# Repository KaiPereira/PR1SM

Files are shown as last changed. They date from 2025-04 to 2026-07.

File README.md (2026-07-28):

# PR1SM - Stacked Acrylic Keyboard

PR1SM is a minimalistic, stacked acrylic keyboard with neopixel backlight, running on KMK. It's built on a cheap, compact 2 layer PCB and has a fully fledged TKL (tenkeyless) layout.

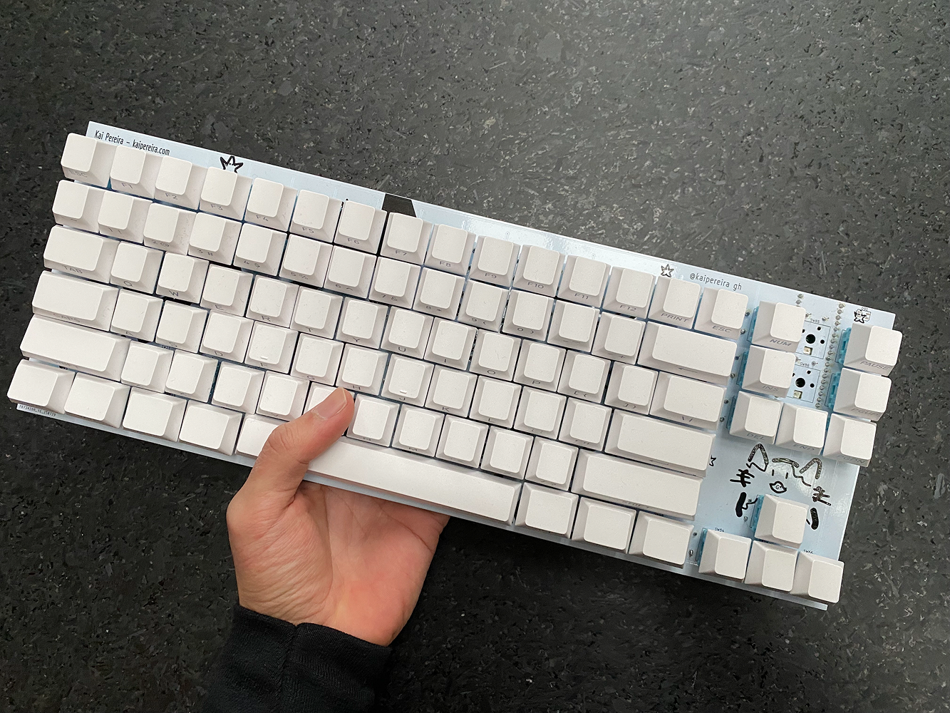
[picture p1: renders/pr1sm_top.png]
Pasted image 20250718024216.png

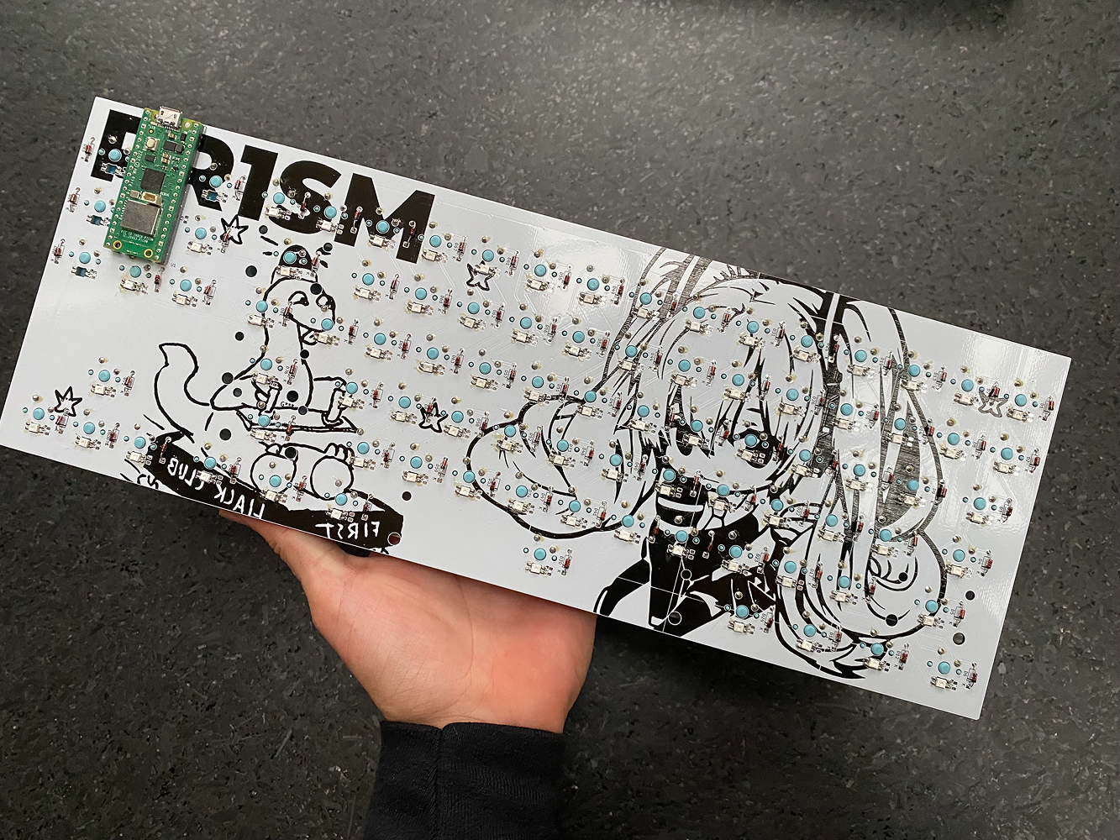
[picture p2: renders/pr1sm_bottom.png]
pr1sm bottom


## Custom Features
- Fully laser cut stacked case that will leak the RGB colors
- Full sized TKL (tenkeyless) layout with a function row
- Complete RGBA backlight on every single key with a power neopixel
- Decoupling caps, and stabilizing resistors for smooth power
- Simply runs off of a Raspberry Pi Pico
- Exposed black silkscreen design on a white PCB

## CAD Design

I used Onshape to design my keyboard like all of my projects. It was a bit tricky, because everything needed to be stock size and was going to be laser cut, so I couldn't have like partially cut in designs that a 3D printer could accomplish.

Anyways the entire case is just held together using M3 screws and it's all stacked so it should be decently rigid. The acrylic will let all the colors through, and it'll look sick.

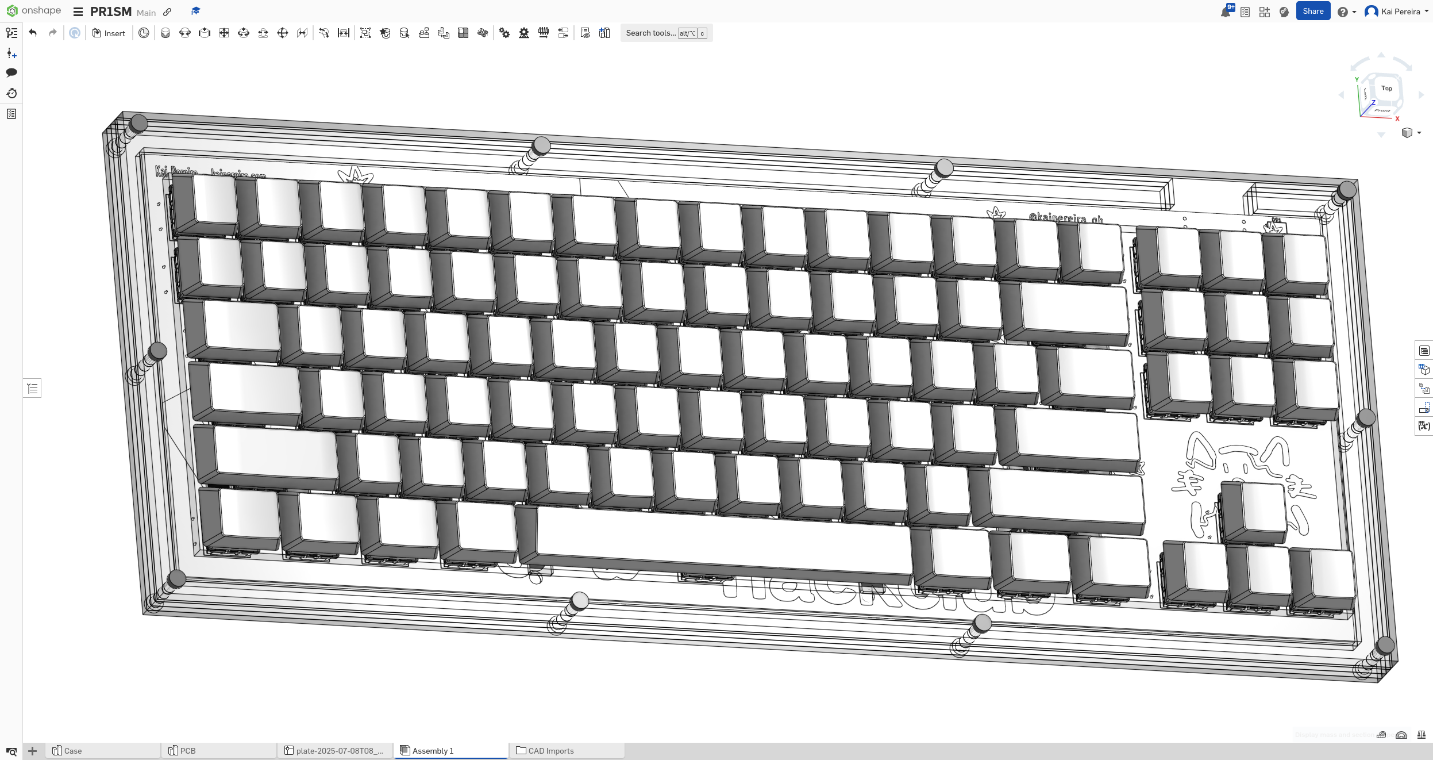
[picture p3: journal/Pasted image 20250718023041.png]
Pasted image 20250718023041.png

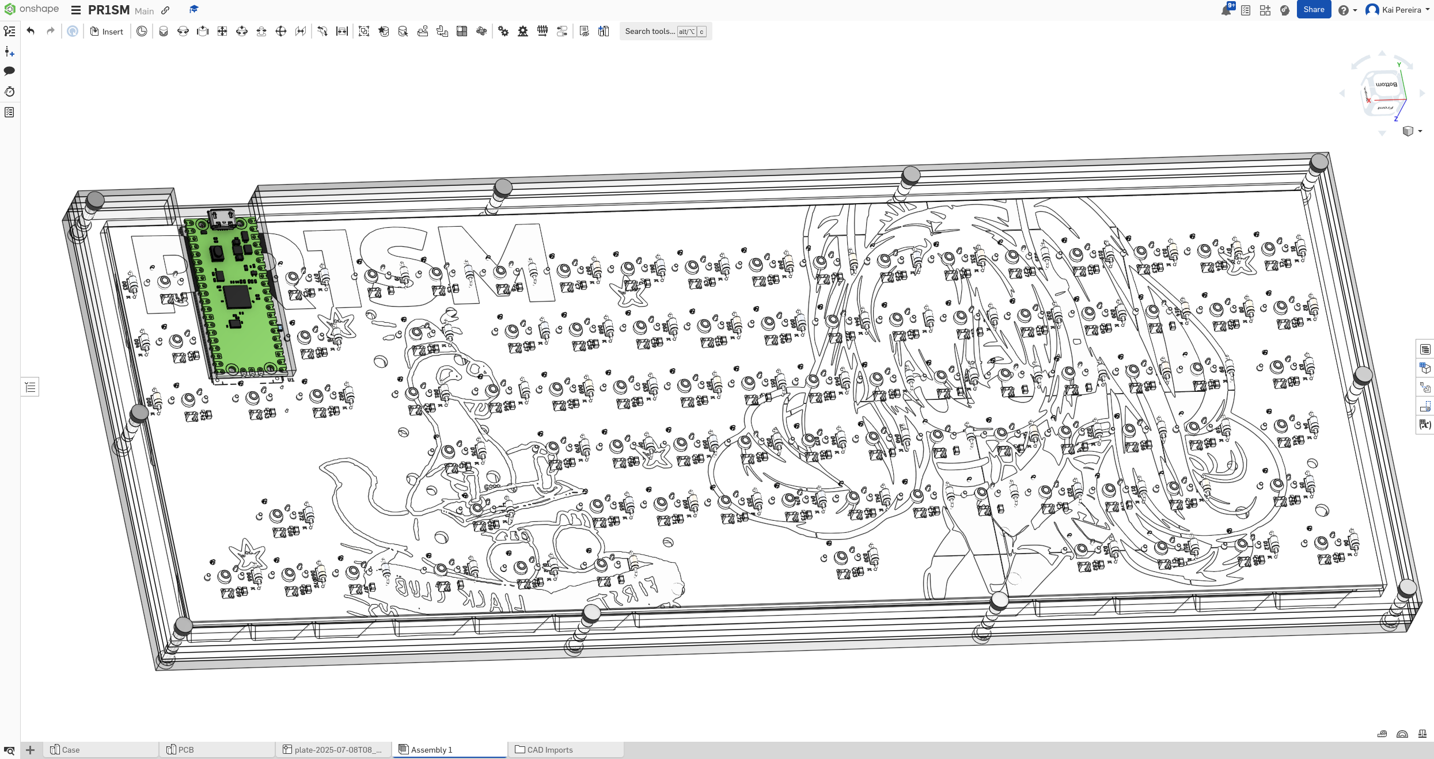
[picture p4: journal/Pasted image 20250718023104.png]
Pasted image 20250718023104.png


*The silkscreen is actually black as shown in the render*

The case is separated into 5 separate laser cut pieces, respectively 3 - 3.5mm, 1 - 1.5mm and 1 - 5mm plate so it's relatively thin and pretty easy to assemble. [Onshape Link](https://cad.onshape.com/documents/8b572caa0e2769c057d91df7/w/f3c5c8a5f25f2593dceb7e8f/e/dc4500617840d95f6da4efee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)

## PCB Design

I designed the entire PCB in KiCad. I tried to stick to all best practices and the neopixels have decoupling and a resistor to smooth voltage. The keys are just a simple key matrix, and the MCU is a Pi Pico. I used the KiCad image converter to do the images, and some of them are drawn by me, others are AI generated and then there's some taken from the internet.

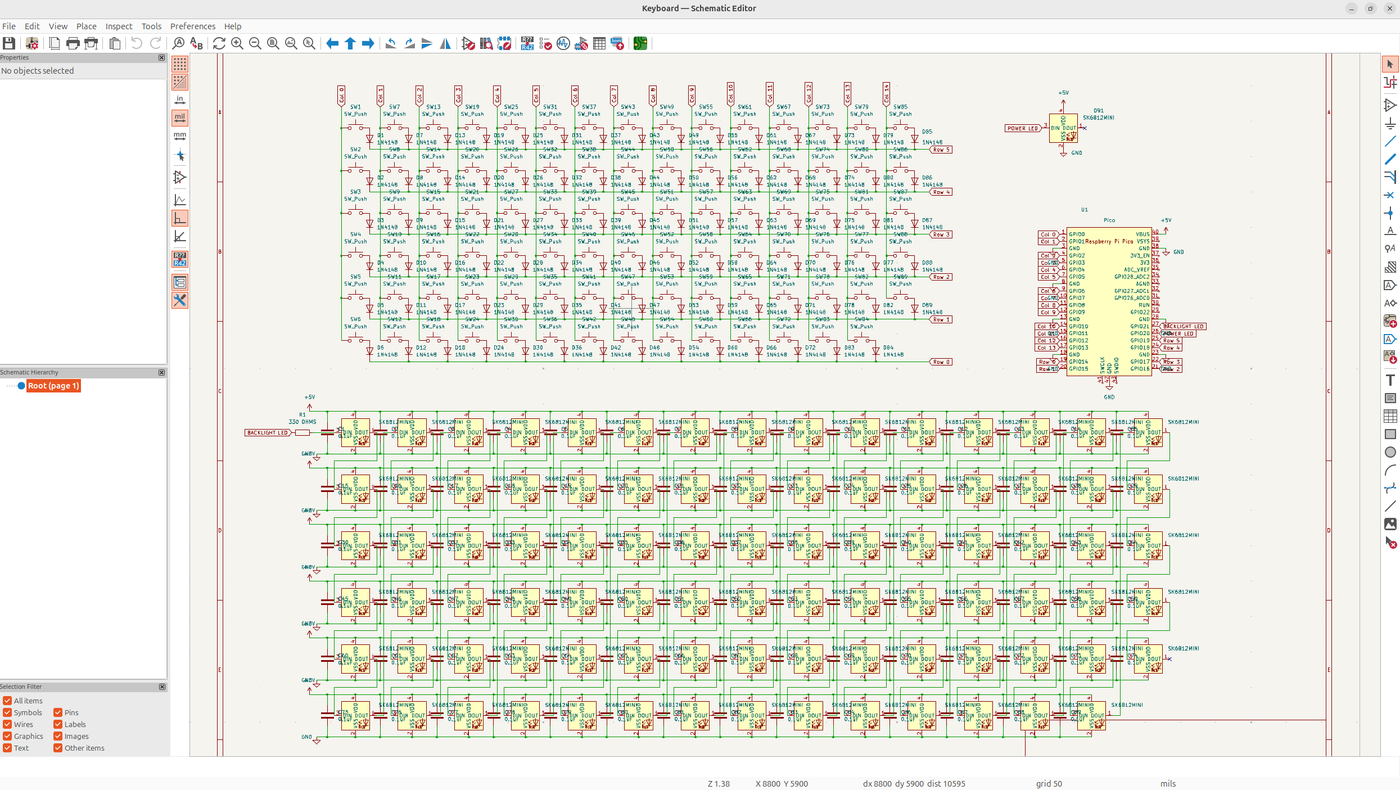
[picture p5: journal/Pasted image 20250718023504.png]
Pasted image 20250718023504.png


Now the PCB is a bit interesting, because it uses a ground fill on the bottom, and then a power fill on the top, the back lines run horizontally, while the front traces run vertically. Via's are on all the neopixel power lines for the fill with the decoupling caps right beside them.

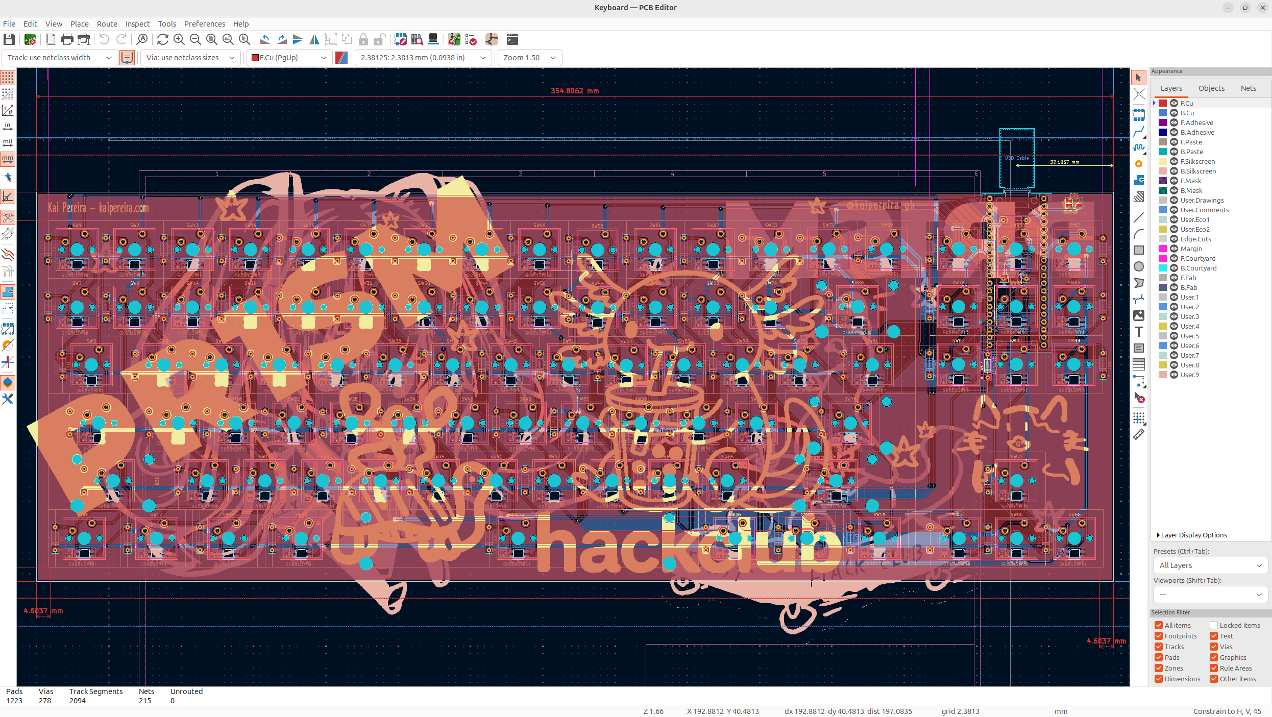
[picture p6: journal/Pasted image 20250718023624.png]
Pasted image 20250718023624.png


Some 3D photo's:

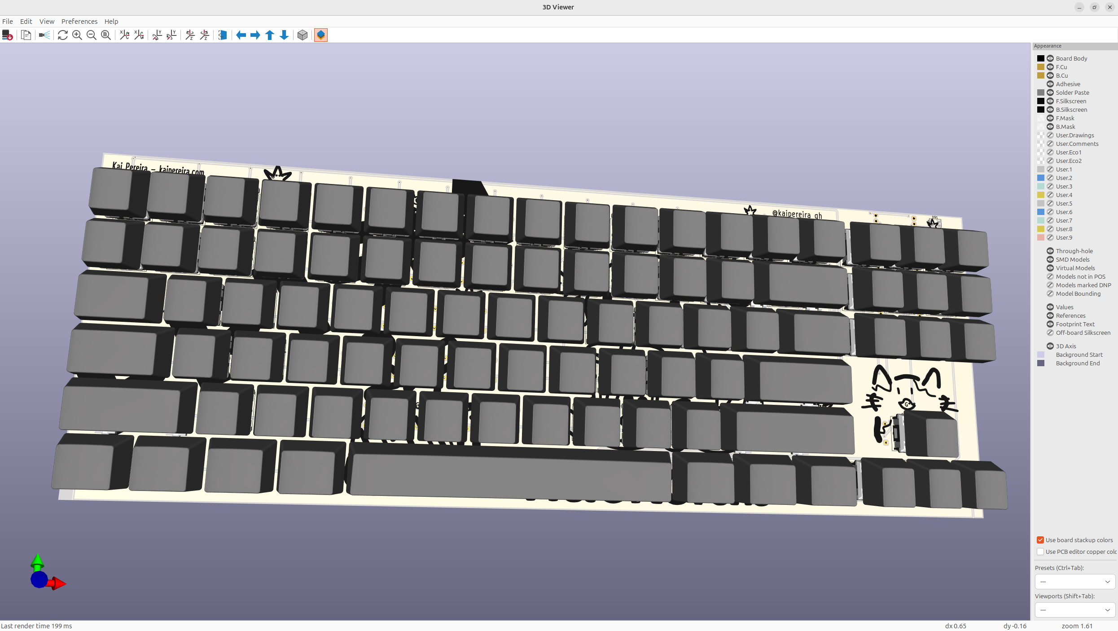
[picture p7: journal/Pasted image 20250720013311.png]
Pasted image 20250720013311.png

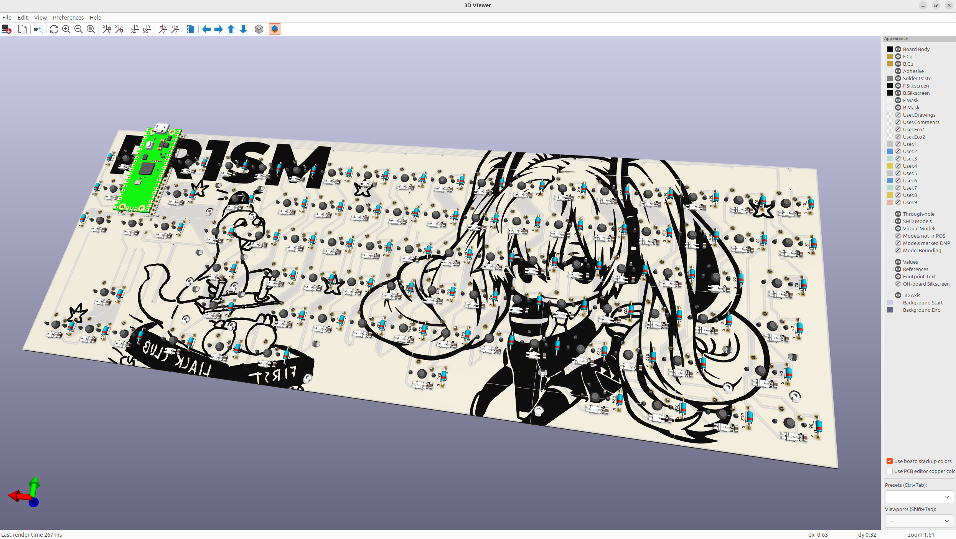
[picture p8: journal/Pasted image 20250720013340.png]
Pasted image 20250720013340.png

## Firmware

PR1SM uses KMK firmware which is written in Python. I programmed all the keys in a matrix and then the backlit neopixels are just running in a wave pattern.

## Bill of Materials (BOM)
Here's everything you'll need to build your own PR1SM keyboard:

| Part | Price | Link |
| --- | ----- | --- |
| 89x Cherry MX Switches | $25 | [Switches](https://www.aliexpress.com/item/1005006255961111.html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) |
| 89x Keycaps for a TKL keyboard | $30 | [Keycaps](https://www.amazon.ca/White-Keycaps-Minimalist-Mechanical-Keyboards/dp/B0BZCB56T5) |
| 90x SK6812 Mini-E LED's | $30 | [Neopixels](https://lcsc.com/product-detail/Light-Emitting-Diodes-LED_OPSCO-Optoelectronics-SK6812MINI-E_C5149201.html) |
| 1x Raspberry Pi Pico | $7 | [Pi Pico](https://www.pishop.ca/product/raspberry-pi-pico-h-pre-soldered-headers/) |
| 3x 3.5mm thick acrylic panels  | Free  | Uni will provide |
| 1x 5mm thick acrylic panel | Free  | Uni will provide |
| 1x 1.5mm thick acrylic panel | Free  | Uni will provide |
| 10x Low profile M3 bolts/nuts  | ?? | Will find locally |
| PCB | $50 | https://jlcpcb.com/ |

Total: Around **$142**

Here's the link to the spreadsheet: https://docs.google.com/spreadsheets/d/1PX1jr134__XBLFXCxBkakxo4KN2pxjdmwIgQ4_i7XN4/edit?usp=sharing

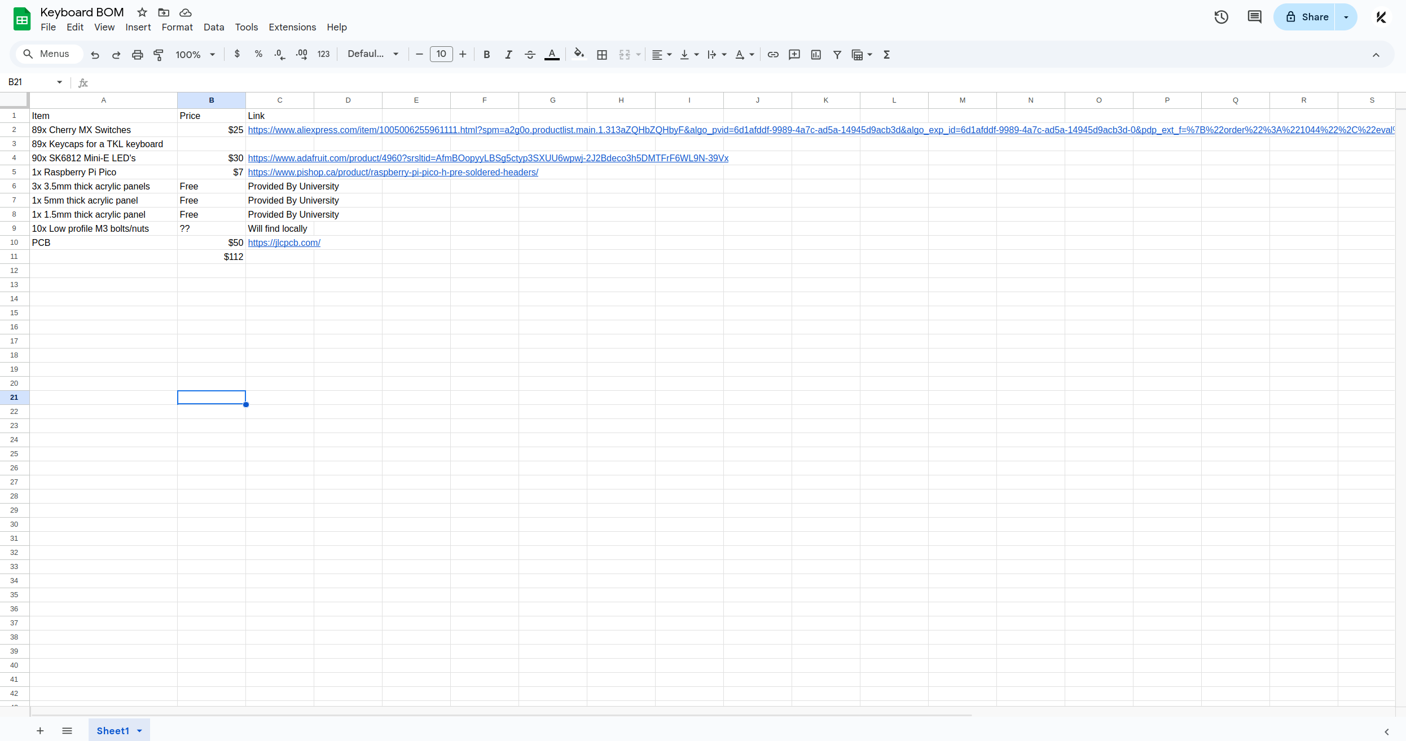
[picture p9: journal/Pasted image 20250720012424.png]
Pasted image 20250720012424.png


## Credits & Help

Thanks to @cheyao and the KiCad discord server for helping me with the wiring and the decoupling caps. @alcovesofastridpark on reddit for the main inspiration for the stacked acrylic and backlight. And of course @qcoral and @acornitum for starting Highway, the program funding this keyboard.

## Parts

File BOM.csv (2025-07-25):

Item | Price | Link
89x Cherry MX Switches | $25 | https://www.aliexpress.com/item/1005006255961111.html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
89x Keycaps for a TKL keyboard | $30 | https://www.amazon.ca/White-Keycaps-Minimalist-Mechanical-Keyboards/dp/B0BZCB56T5
90x SK6812 Mini-E LED's | $30 | https://lcsc.com/product-detail/Light-Emitting-Diodes-LED_OPSCO-Optoelectronics-SK6812MINI-E_C5149201.html
1x Raspberry Pi Pico | $7 | https://www.pishop.ca/product/raspberry-pi-pico-h-pre-soldered-headers/
3x 3.5mm thick acrylic panels | Free | Provided By University
1x 5mm thick acrylic panel | Free | Provided By University
1x 1.5mm thick acrylic panel | Free | Provided By University
10x Low profile M3 bolts/nuts | ?? | Will find locally
PCB | $50 | https://jlcpcb.com/
 | $142

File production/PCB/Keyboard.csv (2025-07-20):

Id | Designator | Footprint | Quantity | Designation | Supplier and ref
1 | SW44,SW56,SW40,SW63,SW11,SW85,SW34,SW8,SW31,SW68,SW46,SW62,SW49,SW45,SW88,SW20,SW54,SW66,SW61,SW78,SW9,SW73,SW64,SW87,SW82,SW15,SW84,SW27,SW67,SW79,SW16,SW58,SW83,SW19,SW23,SW33,SW2,SW7,SW38,SW52,SW53,SW32,SW1,SW60,SW10,SW57,SW41,SW74,SW22,SW55,SW43,SW72,SW14,SW29,SW86,SW21,SW51,SW37,SW47,SW25,SW70,SW26,SW50,SW59,SW89,SW75,SW13,SW28,SW17,SW65,SW69,SW77,SW35,SW39 | SW_Cherry_MX_1.00u_PCB | 74 | SW_Push
2 | D148,D144,D141,D157,D153,D117,D125,D96,D110,D165,D104,D93,D169,D130,D174,D179,D167,D90,D120,D121,D101,D119,D170,D151,D94,D164,D176,D163,D132,D118,D159,D116,D175,D137,D172,D97,D99,D109,D140,D103,D160,D154,D171,D168,D138,D155,D105,D112,D127,D135,D131,D133,D126,D95,D156,D177,D92,D123,D161,D152,D100,D124,D98,D147,D102,D129,D146,D139,D113,D115,D108,D145,D106,D149,D162,D143,D142,D128,D107,D166,D178,D111,D173,D122,D136,D134,D150,D158,D114 | MX_SK6812MINI-E_REV | 89 | SK6812MINI
3 | SW36,SW24,SW42,SW18,SW48,SW6,SW12 | SW_Cherry_MX_1.25u_PCB | 7 | SW_Push
4 | SW30 | SW_Cherry_MX_6.25u_PCB | 1 | SW_Push
5 | SW81,SW3 | SW_Cherry_MX_1.50u_PCB | 2 | SW_Push
6 | SW80 | SW_Cherry_MX_2.00u_PCB | 1 | SW_Push
7 | D87,D50,D36,D43,D86,D51,D70,D21,D35,D79,D27,D88,D24,D71,D66,D64,D60,D42,D73,D29,D39,D54,D67,D38,D47,D2,D65,D48,D76,D82,D14,D8,D33,D68,D22,D55,D58,D56,D89,D80,D37,D9,D30,D7,D11,D81,D31,D13,D25,D1,D28,D57,D19,D6,D18,D41,D52,D17,D63,D5,D59,D78,D85,D20,D3,D23,D44,D4,D77,D49,D69,D53,D45,D12,D32,D46,D74,D84,D10,D40,D26,D16,D34,D61,D62,D15,D83,D72,D75 | D_DO-35_SOD27_P7.62mm_Horizontal | 89 | 1N4148
8 | SW5,SW76 | SW_Cherry_MX_2.25u_PCB | 2 | SW_Push
9 | SW71 | SW_Cherry_MX_2.75u_PCB | 1 | SW_Push
10 | SW4 | SW_Cherry_MX_1.75u_PCB | 1 | SW_Push
11 | D91 | LED_SK6812MINI_PLCC4_3.5x3.5mm_P1.75mm | 1 | SK6812MINI
12 | C59,C42,C19,C56,C7,C36,C49,C50,C83,C64,C27,C61,C2,C87,C32,C18,C21,C28,C23,C78,C1,C68,C84,C44,C85,C55,C89,C81,C10,C45,C31,C43,C88,C47,C86,C66,C39,C3,C54,C35,C37,C62,C9,C38,C41,C75,C5,C79,C12,C82,C24,C11,C52,C25,C17,C65,C48,C33,C51,C63,C60,C26,C13,C20,C4,C67,C14,C53,C70,C29,C71,C72,C22,C46,C58,C40,C8,C69,C34,C6,C77,C16,C74,C76,C15,C80,C30,C73,C57 | C_0805_2012Metric | 89 | 0.1uF
13 | R1 | R_0805_2012Metric | 1 | 330 OHMS
14 | U1 | RaspberryPi_Pico_Common_THT_BACKSIDE | 1 | Pico

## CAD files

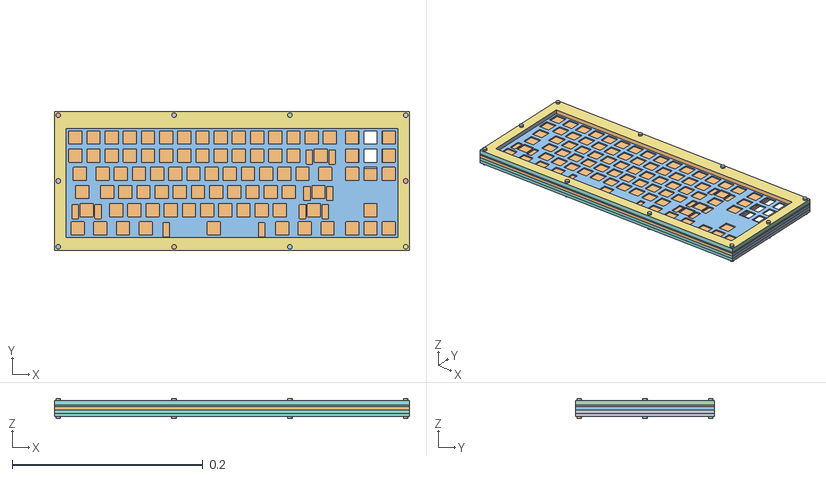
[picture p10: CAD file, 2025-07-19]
CAD/Full Case/Full Case.obj
0.372 x 0.146 x 0.021

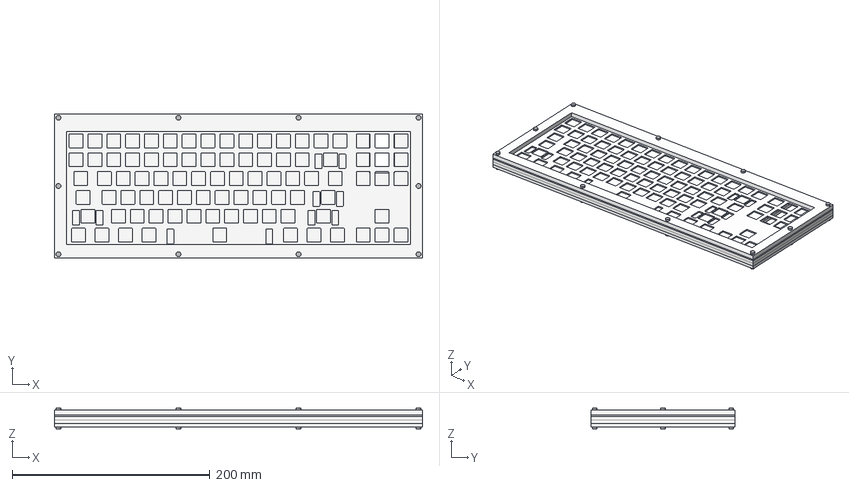
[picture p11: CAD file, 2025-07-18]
production/Full Case.step
372.0 x 146.0 x 21.0 mm

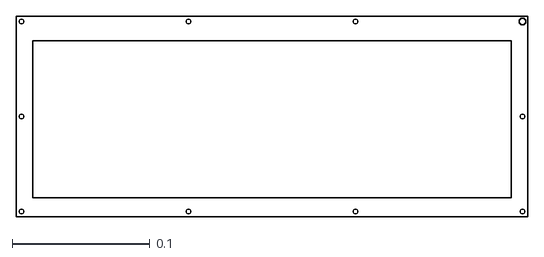
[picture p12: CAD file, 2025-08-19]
CAD/DXF's/5mm TOP.dxf
0.372 x 0.146

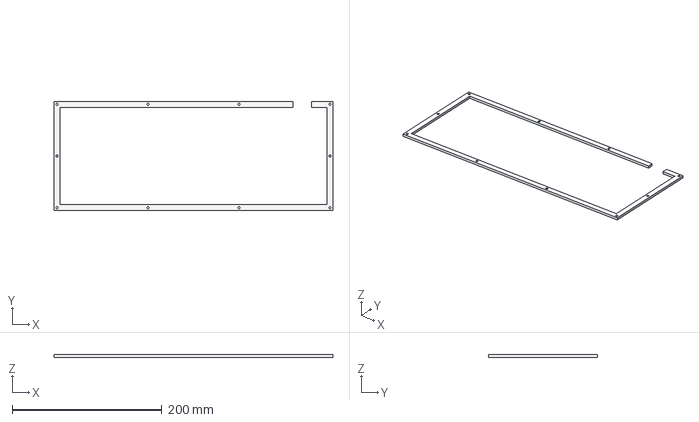
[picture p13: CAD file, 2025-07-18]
CAD/STEPS/Layer 2 Case.step
372.0 x 146.0 x 3.50 mm

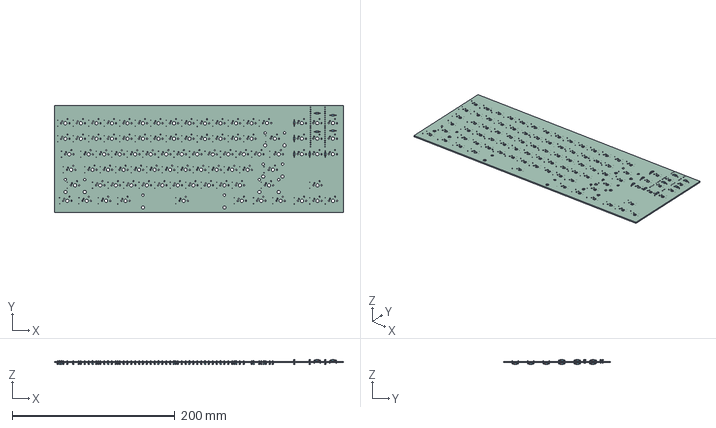
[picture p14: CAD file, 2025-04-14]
Keyboard.step
354.8 x 131.0 x 6.72 mm
D_DO-35_SOD27_P7.62mm_Horizontal x 88
Keyboard_PCB

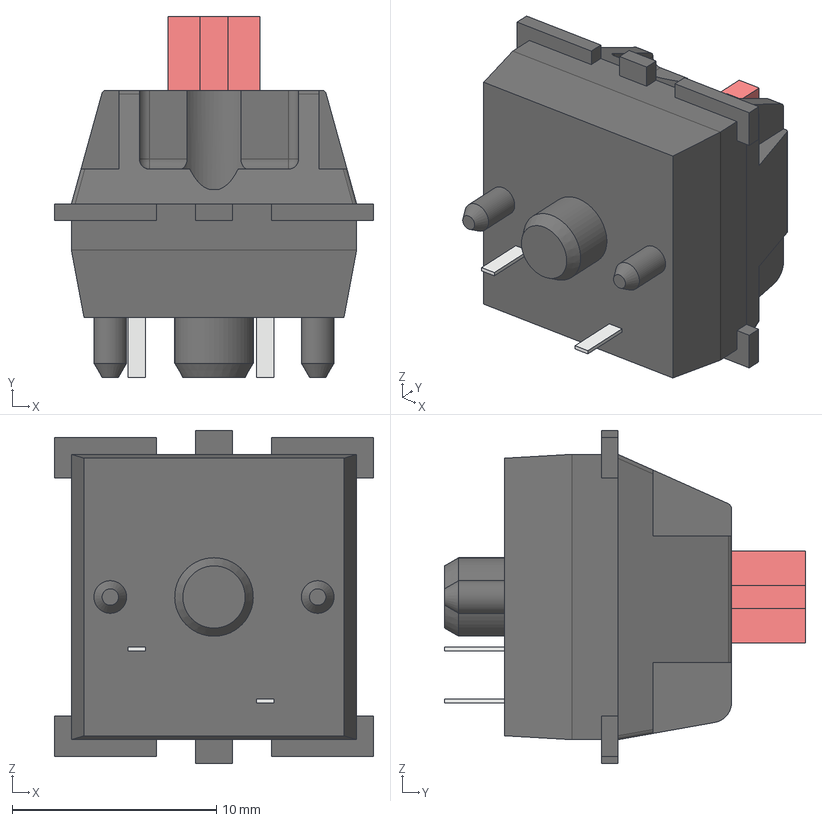
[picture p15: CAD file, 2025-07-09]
PCB/switch.step
15.6 x 17.7 x 16.3 mm

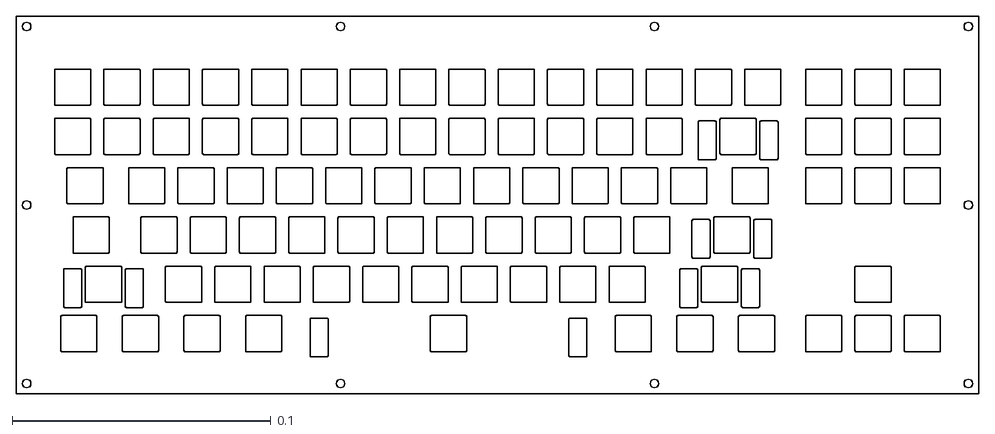
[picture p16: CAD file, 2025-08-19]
CAD/DXF's/1.5mm PLATE.dxf
0.372 x 0.146

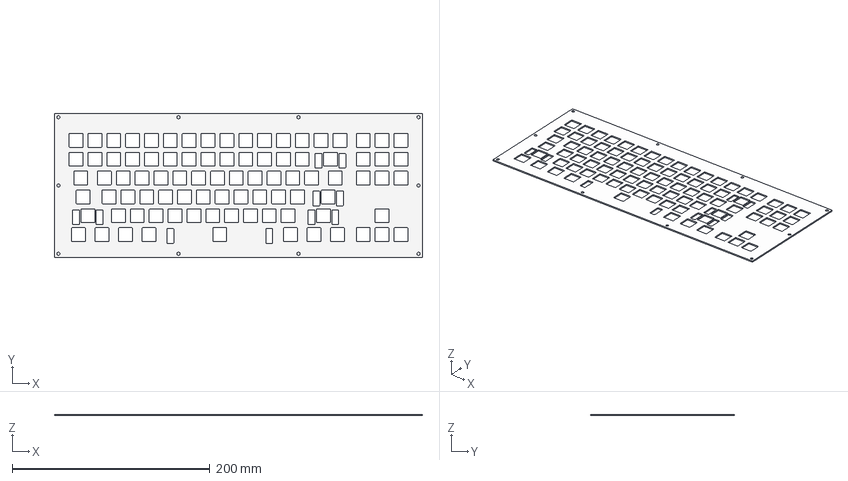
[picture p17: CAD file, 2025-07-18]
CAD/STEPS/Layer 4 Case.step
372.0 x 146.0 x 1.50 mm

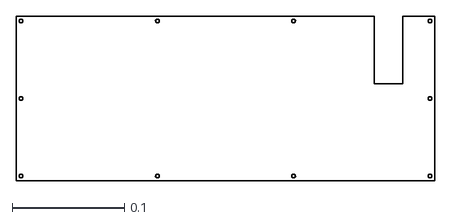
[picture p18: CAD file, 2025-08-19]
CAD/DXF's/3.5mm BOTTOM.dxf
0.372 x 0.146

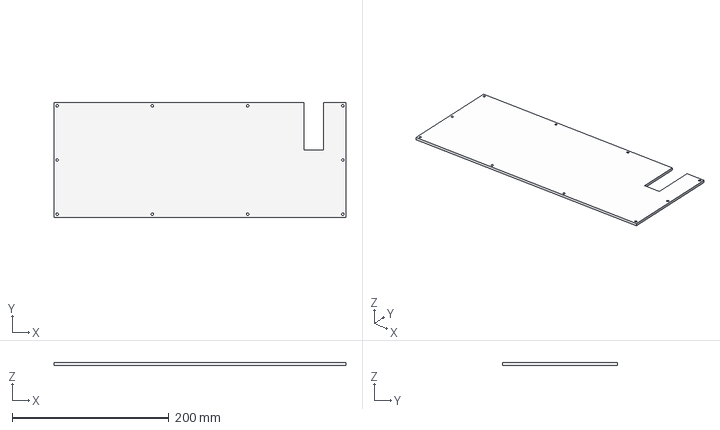
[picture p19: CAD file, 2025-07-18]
CAD/STEPS/Layer 1 Case.step
372.0 x 146.0 x 3.50 mm

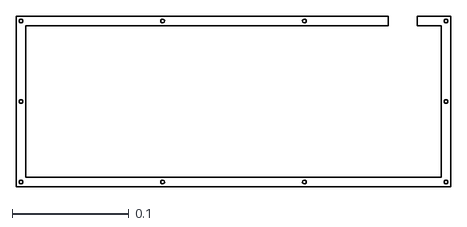
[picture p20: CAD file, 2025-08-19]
CAD/DXF's/3.5mm SPACER-PRINT_2.dxf
0.372 x 0.146

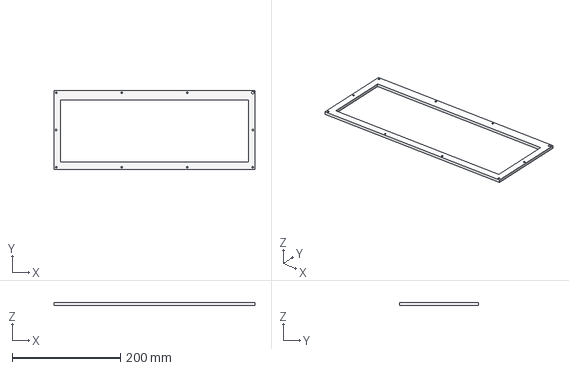
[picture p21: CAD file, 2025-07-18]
CAD/STEPS/Layer 5 Case.step
372.0 x 146.0 x 5.00 mm

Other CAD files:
CAD/STEPS/Layer 3 Case.step
renders/render.blend

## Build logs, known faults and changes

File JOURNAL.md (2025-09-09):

---
title: PR1SM
author: Kai Pereira
description: " A minimalic, stacked fully backlit acrylic keyboard using a small 2 layer pcb"
created_at: 2025-07-07
---
**Total Time Spent: 23 Hours**
## Day 1 -  PCB Schematic - 3 Hours - July 7th

The PR1SM keyboard is going to be a simple, stacked acrylic keyboard that will have some back-lighting. I want a blend of functionality and aesthetic so I'm going with a more simple design that's still decently complex.

I'm going to take inspiration from the MX Mechanical keyboard for the layout and just remove the numpad, because let's be honest, no one uses that.

So let's get started with a simple layout. I'm just going to be using a Pi Pico or maybe an Orpheus Pico, but they have the same footprint so I'll just stick with a Pi Pico for now.

I did the math for the keys and there's 89 in total, so let's add all of those on.

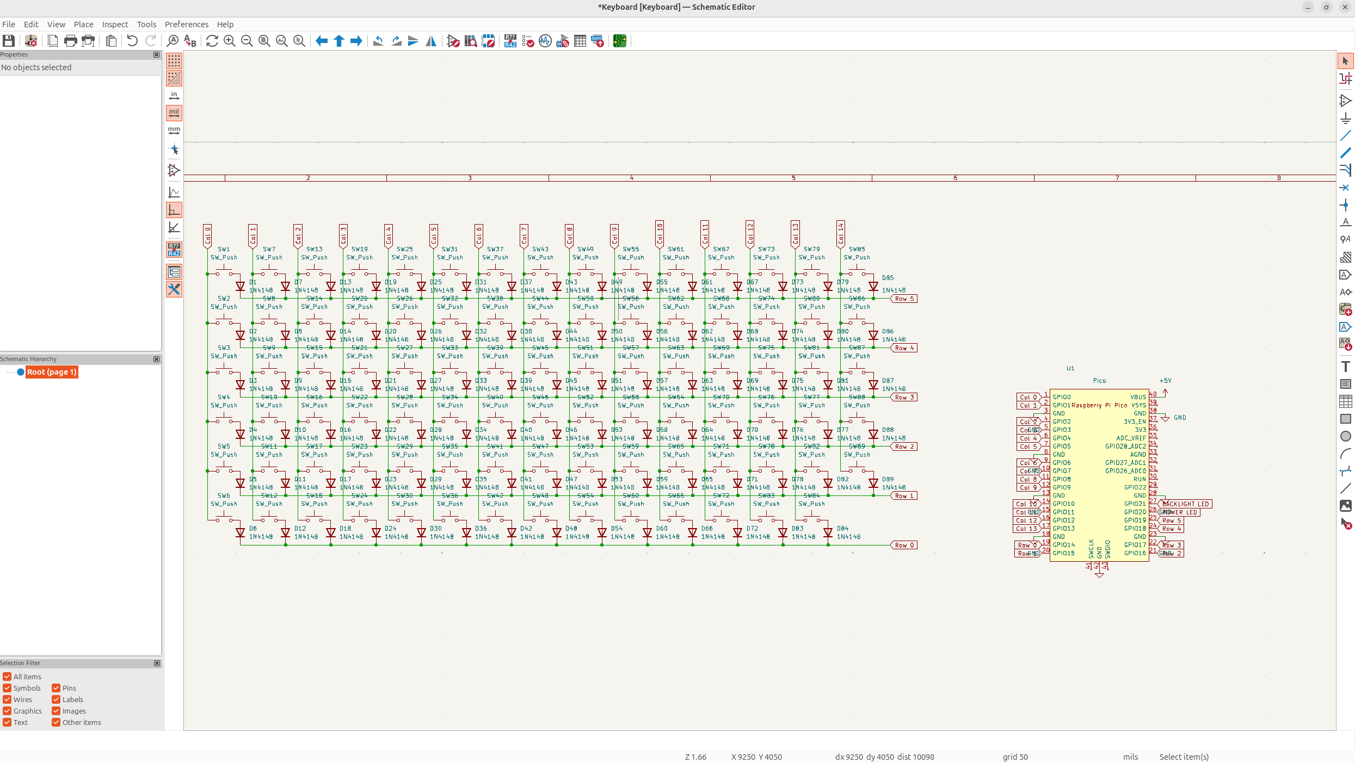
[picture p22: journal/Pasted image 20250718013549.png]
Pasted image 20250718013549.png


Next I want to have a small power LED, I'm just going to make this separate so I don't need to do some annoying programming, and also because it's got a different footprint so it makes a bit more sense.

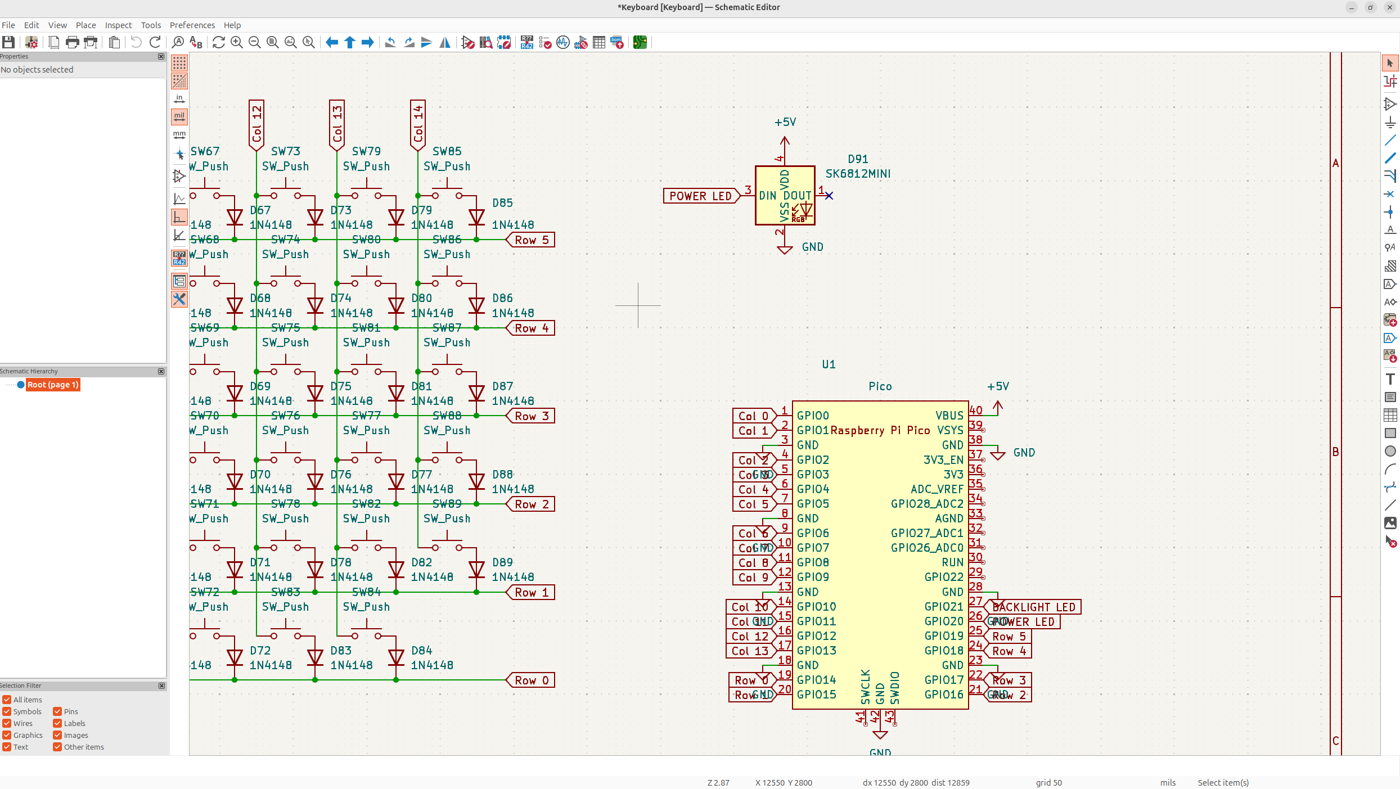
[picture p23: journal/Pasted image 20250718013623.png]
Pasted image 20250718013623.png


Next I need to add all the neopixels. I need one for every single key, and I'm going to put a 330 Ω resistor on the data line to smooth the connection out, and then I'm also going to use decoupling capacitors to stabilize the power a bit. The caps are just going to be 0.1uF ceramic caps.

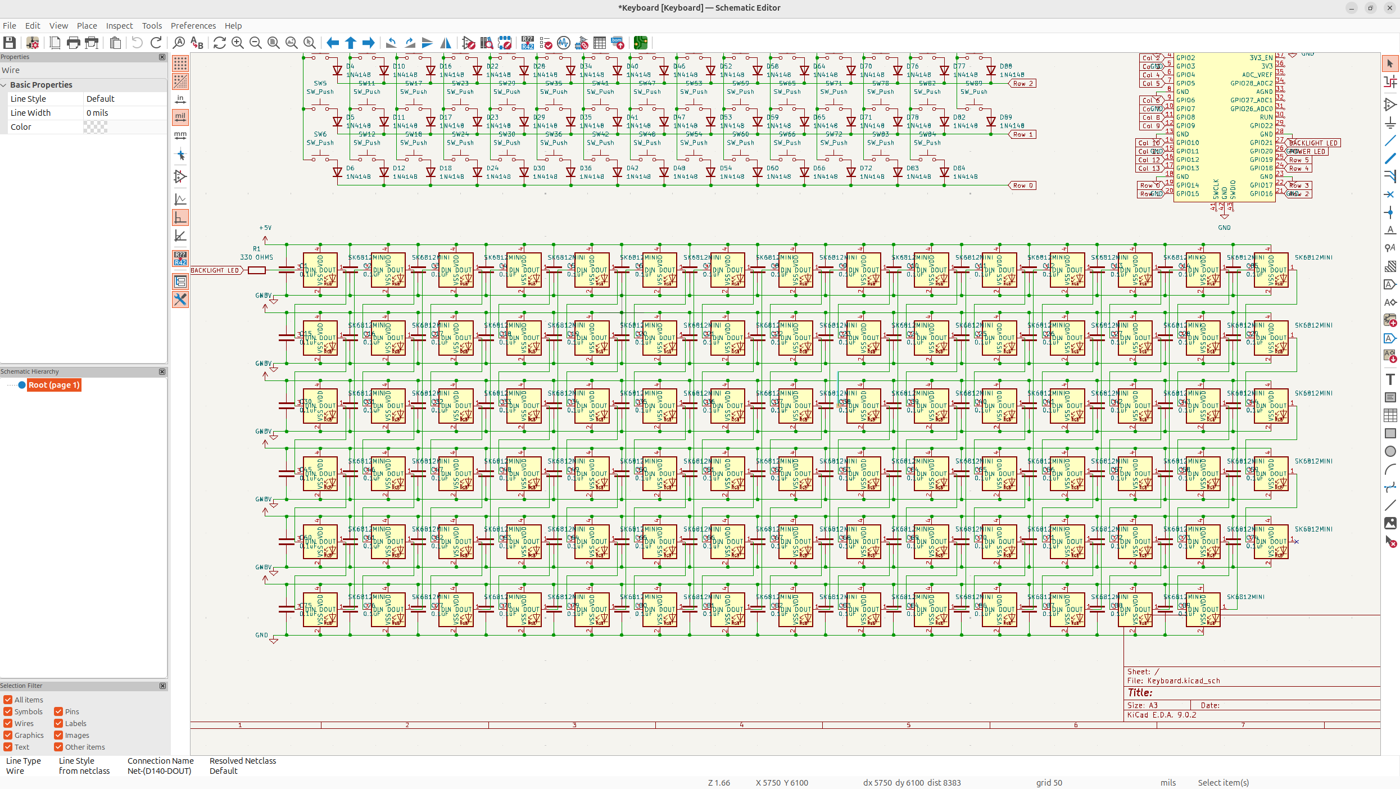
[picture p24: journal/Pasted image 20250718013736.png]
Pasted image 20250718013736.png


Now that's the entire schematic done. I wanted to stick to best practices, and I personally think it's pretty clean, but I went through quite a bit of variations just to make sure I had the right amount of neopixels and keys so it took quite a long time.

## Day 2 - PCB Wiring - 8 Hours

Next I needed to wire the PCB, now I'm just going to describe the process of wiring the final one, but I will say, I re-wired the entire thing over 4 times because I wanted it to be pretty clean and stick to good practices.

Now this PCB still isn't perfect, it actually has a lot of flaws, but I think it's a pretty good way of doing it for a 2 layer board.

So what I've decided to do for this board, is have a ground fill on the bottom, and then put via's on all the neopixels power, and do a power fill on top. This will give good voltage to the neopixels, while being pretty clean, and the ground will reduce the noise, which I believe will lead to a pretty nice board.

But anyways, first I had to do the layout. I just set a 2.38125mm grid and then halved that for smaller parts.

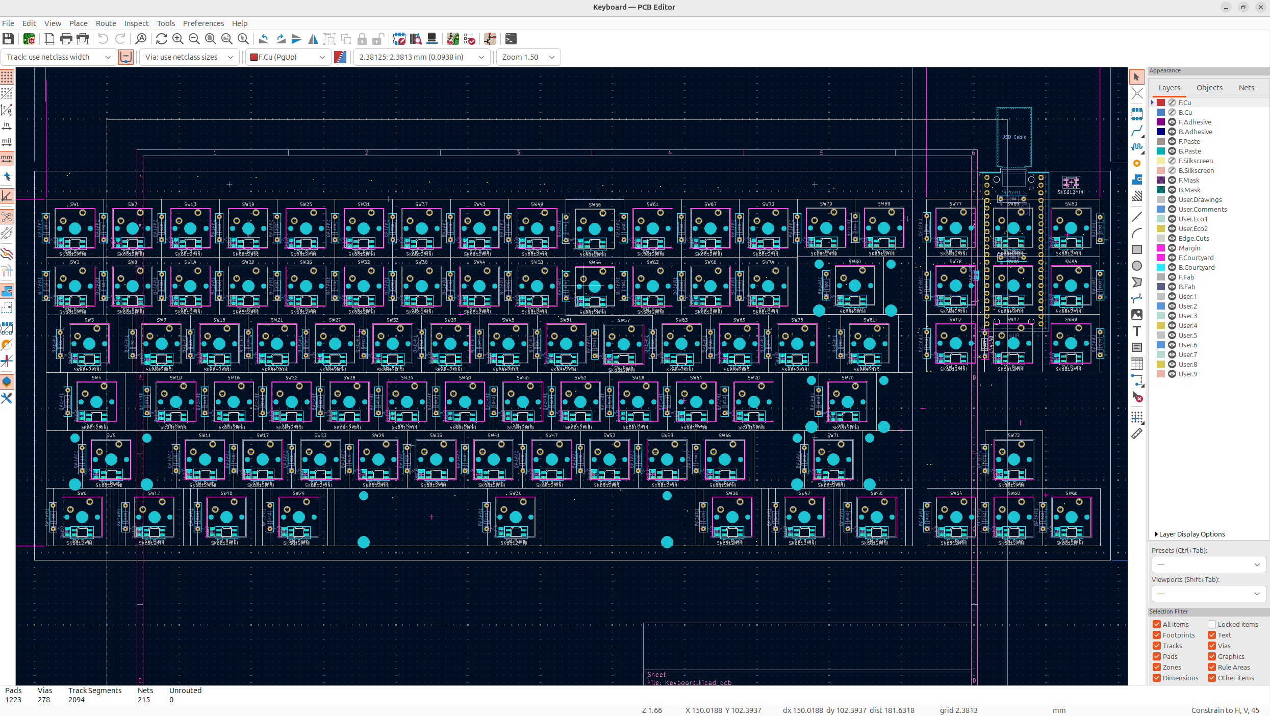
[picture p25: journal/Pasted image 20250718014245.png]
Pasted image 20250718014245.png


You can see it's a pretty clean PCB, I used reverse mount footprints for the neopixels and then I put the Pico on the back under the keys to maximize space, and I know it'll look really good the actual PCB. Though the PCB will probably bring up some issues because some of the resistors are there, so I need to solder it with enough of a gap for the resistors. 

I also need to leave some space underneath the case for the Pi Pico to sit, so it might be a bit annoying, but I kind of like how this will make the actual keyboard look good.

The neopixel footprint was taking from [ebastler's](https://github.com/ebastler/kicad-keyboard-parts.pretty) repository and they're just mounted underneath cherry mx keys which will specifically have holes for the neopixels.

Anyways now that everything was placed, I need to wire everything. I kept with doing back lines going horizontal and then red lines going vertical, which is a really nice way of wiring stuff.

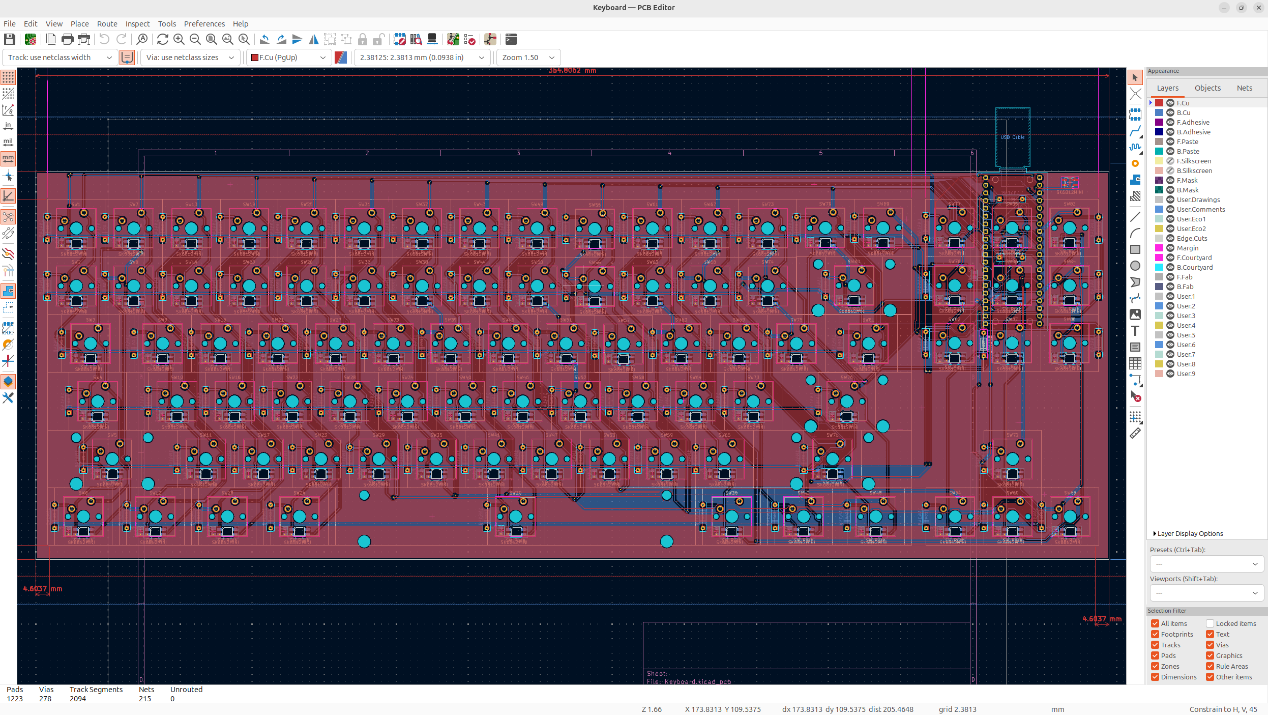
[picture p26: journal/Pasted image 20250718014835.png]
Pasted image 20250718014835.png


Then after that, I added via's to all the neopixel power lines, and did the ground fill on the bottom and the power fill on the top layer. Now I've used around 300 via's and 2100 line segments... but it'll be fine hopefully.

It's quite a complicated to wire board for just 2 layers, but it should be okay, and will hopefully look good.

You can also see, I wired the resistor as close to the start of the data line as possible, which is crucial.

Then I put the decoupling capacitors right next to the power lines of the neopixels along the power fill.

I had a lot of thermal relief errors when doing this, but to fix them, I just adjusted the lines so the fill could pass through. I might've had less of these if I switched which side was ground, and which side was power.

Anyways, next I had to add silkscreen and colors. I opted to go for a white board, with black silkscreen because I feel like a stacked acrylic keyboard is pretty clean, so it'll look sick.

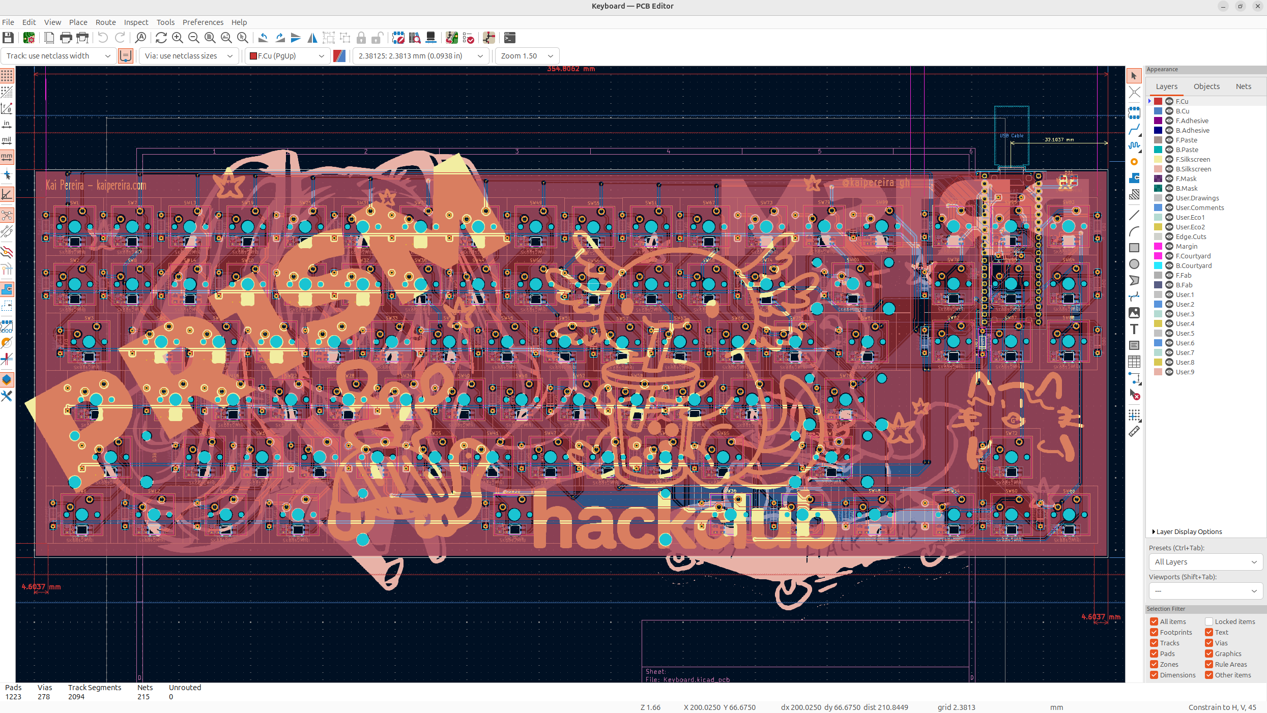
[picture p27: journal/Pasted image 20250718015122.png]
Pasted image 20250718015122.png


I drew/made half of these, and then AI generated/found the rest of the designs for the silkscreen. And I think the board turned out really well!

But before I took the 3D model of the keyboard, I needed to add 3D models to all of the footprints which took quite a long time, but it wasn't too bad.

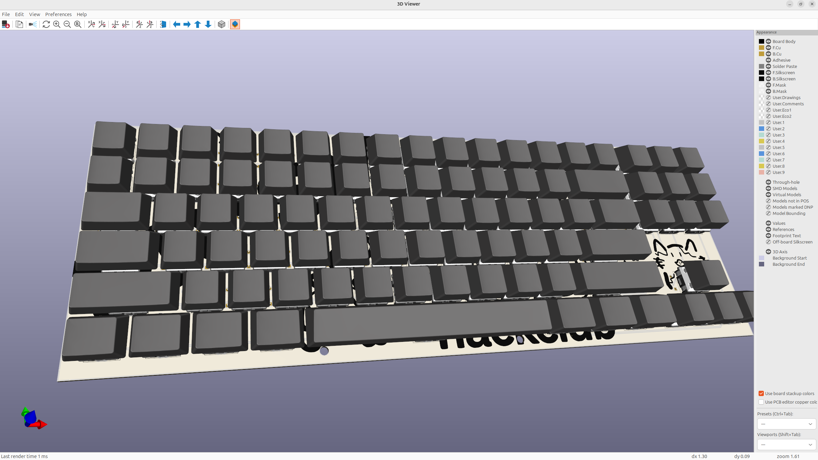
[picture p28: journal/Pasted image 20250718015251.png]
Pasted image 20250718015251.png


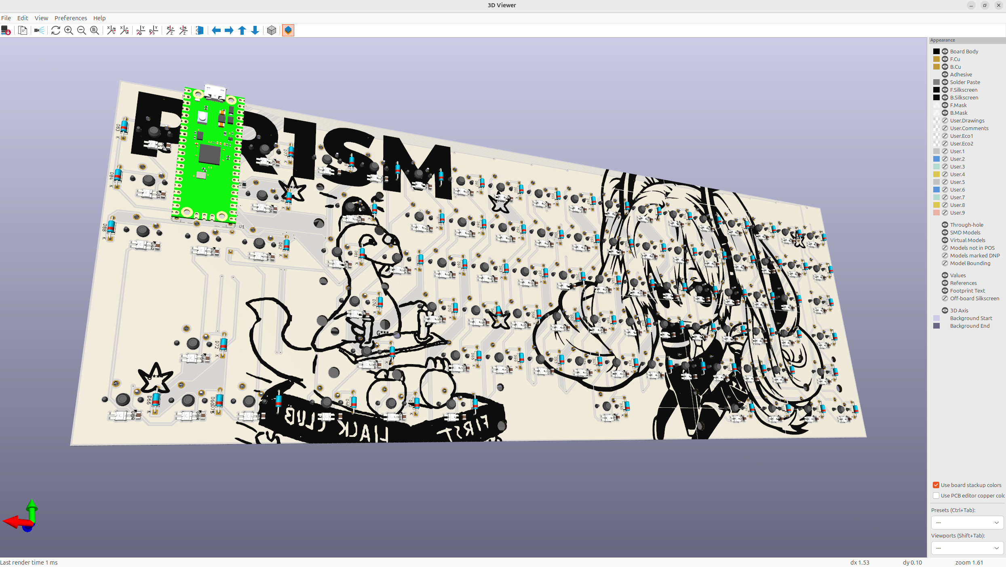
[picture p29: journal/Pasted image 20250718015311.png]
Pasted image 20250718015311.png


And personally, I think this board looks absolutely sick, the branding text on the board, really makes it beautiful!

Anyways, this took me 4 times to wire because of small mistakes, so always plan out your wiring a bit more beforehand guys!

## Day 3 - CAD Design - 6 Hours

Now I wanted to go with a stacked acrylic case which was actually more annoying to make than I thought it would be. But anyways, I sketched out the entire keyboard because I knew that I could make the entire case in one sketch conveniently.

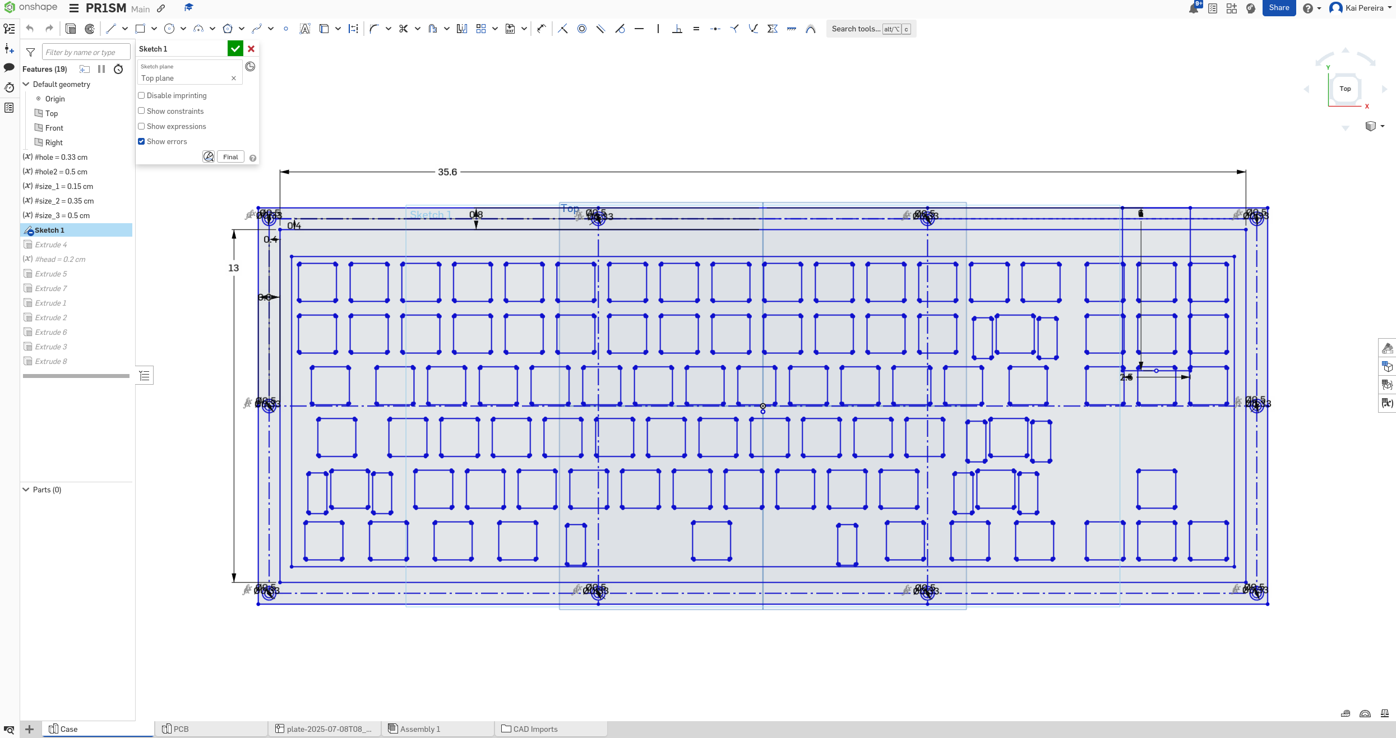
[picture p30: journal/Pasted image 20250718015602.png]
Pasted image 20250718015602.png


Now this sketch took me quite a few iterations, but I got the clearance on point and it looks pretty good. The main problem I was having was aligning the plate with the PCB, and for some reason, that took me a decent amount of time.

Now I needed to actually make the case, the thing about making a stacked acrylic case, is it needs to be decently thin, but also still have all the necessary layers. I also needed to design it, so it's easy to lasercut, and so everything fit pretty tightly. And after a bit of iteration, I got this beautiful board.

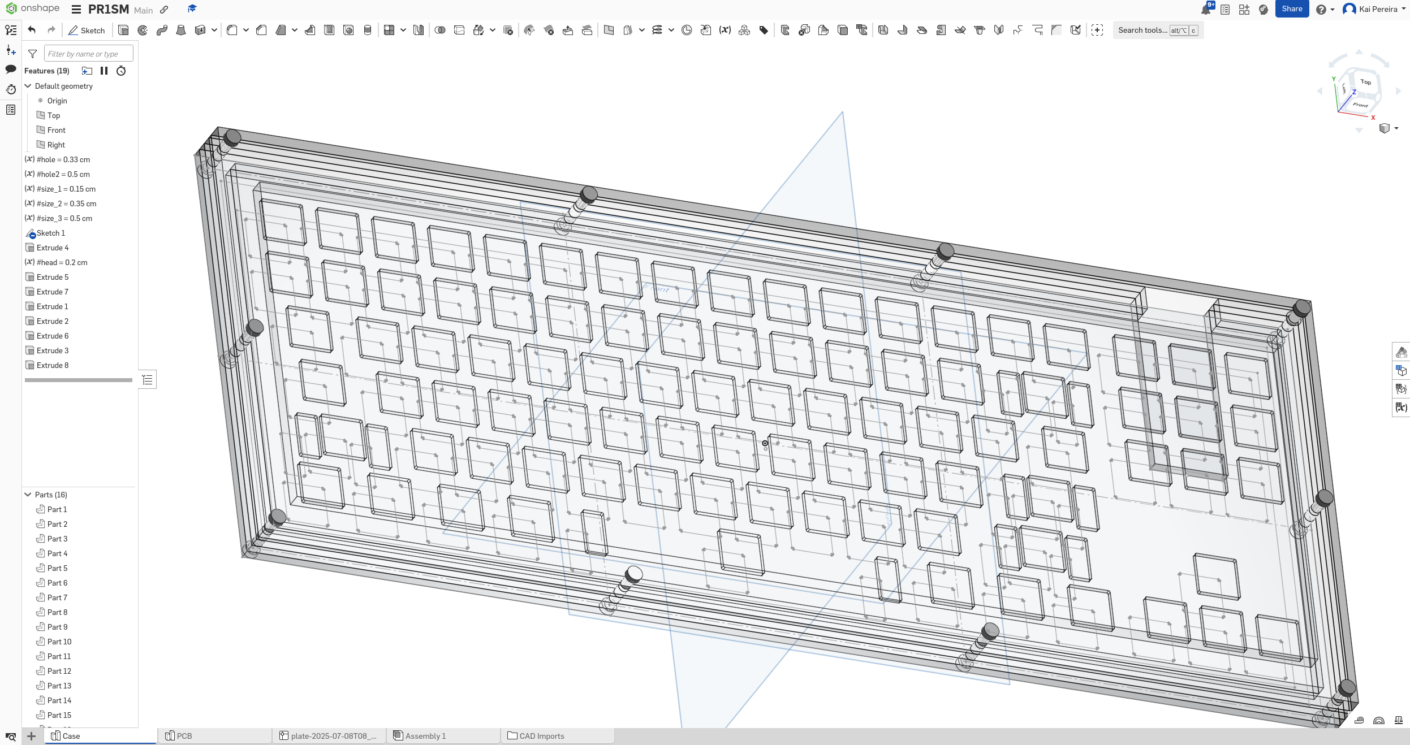
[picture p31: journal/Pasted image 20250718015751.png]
Pasted image 20250718015751.png


It uses stock 5mm, 3.5mm and 1.5mm thick acrylic and then classic M3 screws to hold the entire thing together. Now I didn't want it to flex too much so I added quite a few screws. I also added a cutout so that the PCB could go through the case nicely and still be able to plug in and such easily.

Now the PCB was extremely laggy because it had lots of models on it, so it took a long time to fasten each time I iterated, but here's how it looks inside of the plate

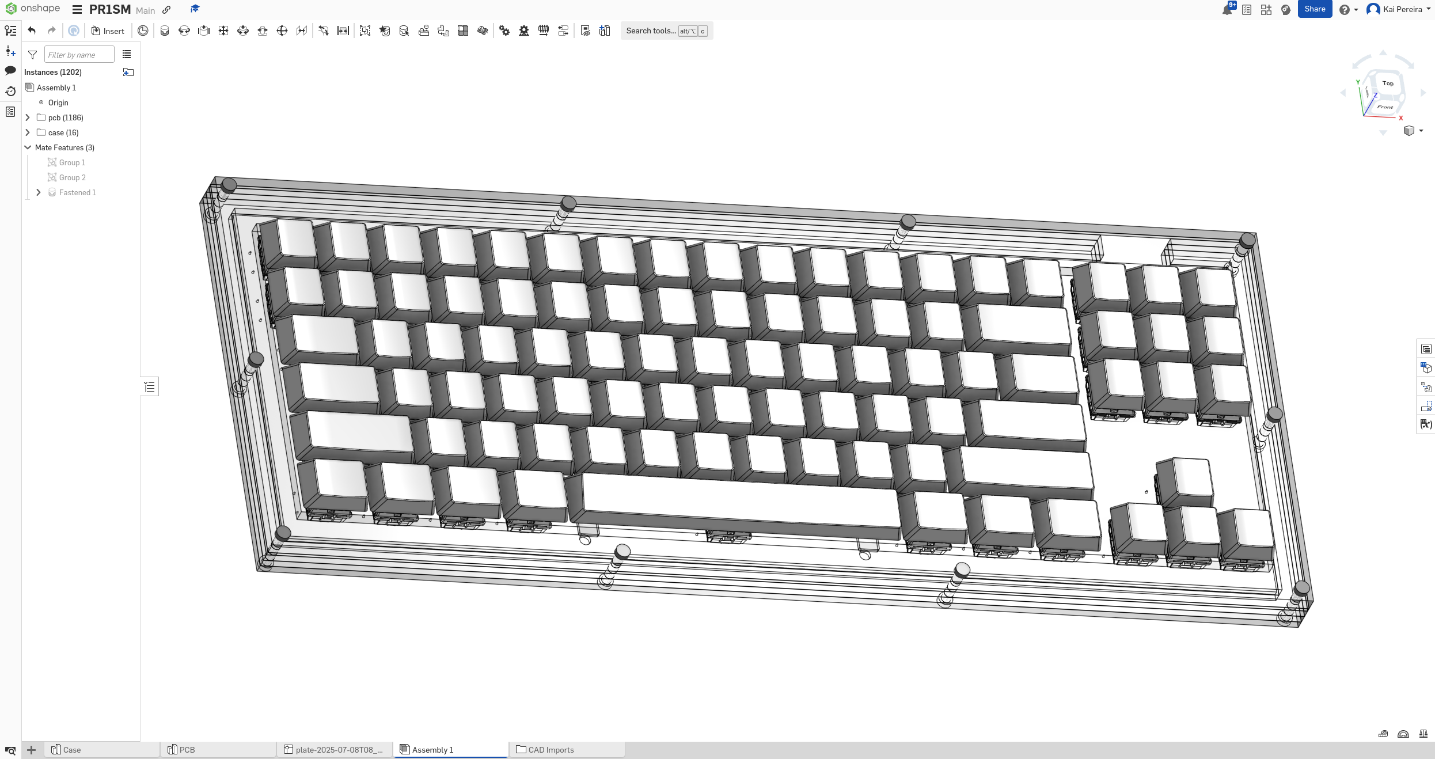
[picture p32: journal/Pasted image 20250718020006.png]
Pasted image 20250718020006.png


I personally think this is pretty clean, and I've taken a look at each section, and everything fits nicely together. And the MCU fits in pretty nicely, now I'm not too sure if it'll actually need this whole, but I'll put it in there for V1 just to be safe.

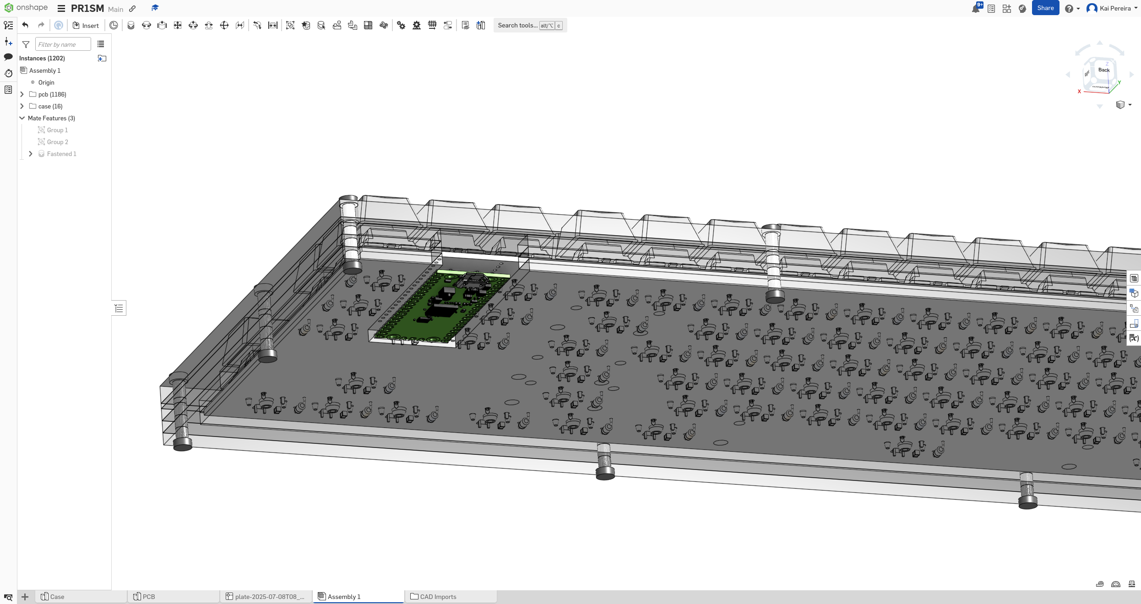
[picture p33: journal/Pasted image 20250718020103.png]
Pasted image 20250718020103.png


It'll be soldered a bit away from the resistors so it has some clearance space.

Now I know that it probably doesn't seem like I spent too long on this case because it's so simple, but I kept on messing up the tolerances, and also I'm not used to making something that fits in so cleanly like this. And it's laser cut, bolted in so a couple more things to take into account instead of just 3D printing it.

## Day 4 - Refining and Rendering - 6 Hours

Anyways before I rendered my project, I needed to add a couple more models to the PCB so that it would look very accurate in the render. So I just added the neopixels and the stabilizers to the PCB model and re-downloaded it. I usually download the PCB as a GLB for blender because it's pretty fast and keeps most of it's details!

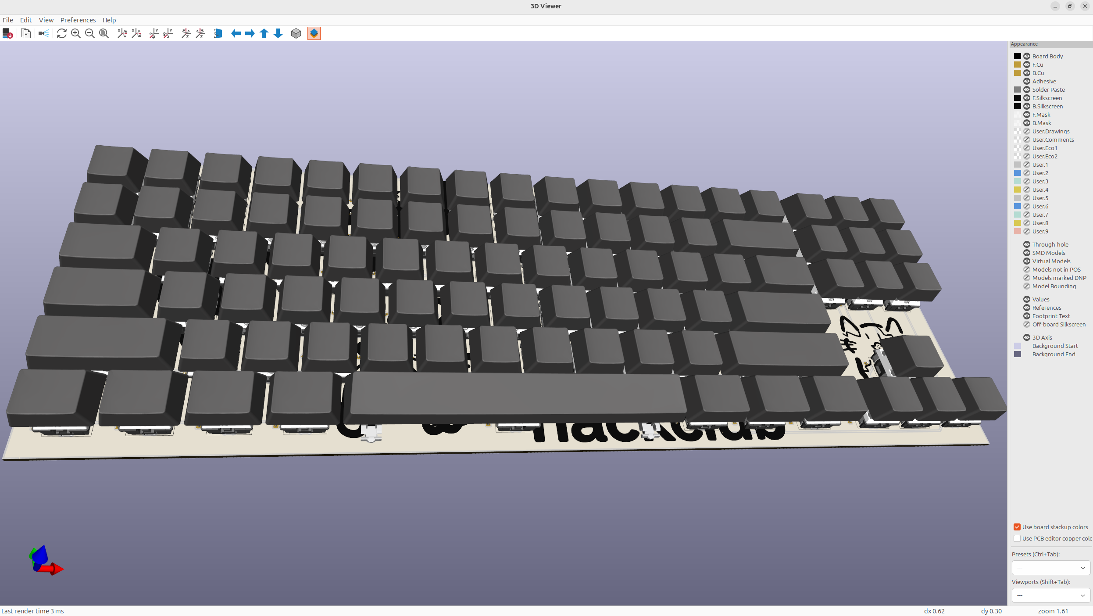
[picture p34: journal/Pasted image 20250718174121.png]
Pasted image 20250718174121.png


So next I started up a new blender project, and I also added all the blender files to LFS so I didn't have issues with large files. You need to remember to add both the ".blender" and the ".blender1" files to LFS.

Then I just added the keyboard model from KiCad as a GLB and we now have the base for our PCB in Blender.

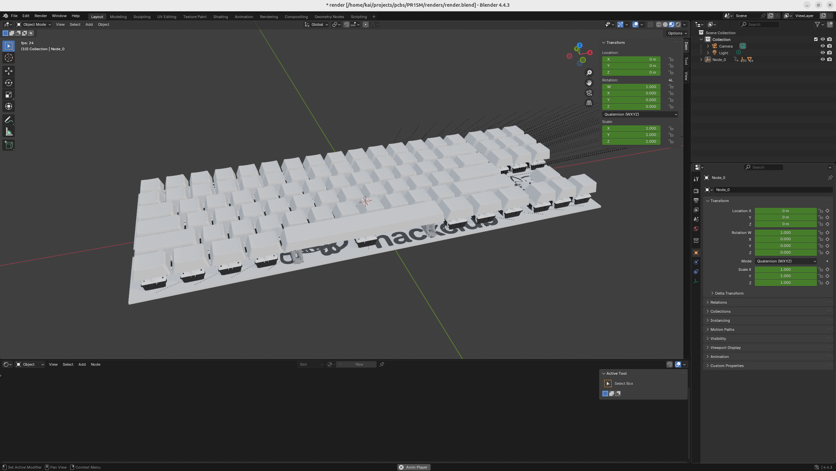
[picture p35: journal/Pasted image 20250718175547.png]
Pasted image 20250718175547.png


After that, I applied a slightly bumpy material to the keycaps and added in the case. The case is just going to be some transparent acrylic, and then I'm just going to make the screws ultra-metallic because I kind of like that style.

After that I added a camera angle, I figured out you could do View -> Align View -> Align active camera to active view, and you could just set the camera to whatever you were currently looking at which looks really good.

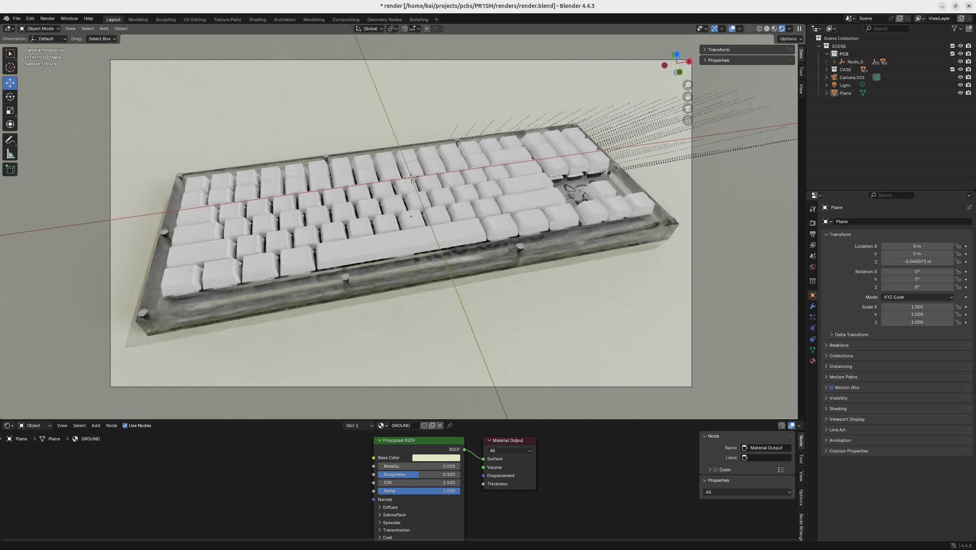
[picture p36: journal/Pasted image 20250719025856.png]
Pasted image 20250719025856.png


Also make sure to render with cycles instead of Eevee because it's way more realistic, and renders transparent materials like glass way more nicely.

Anyways now I'm going to actually render the image, and let's see how it turns out!

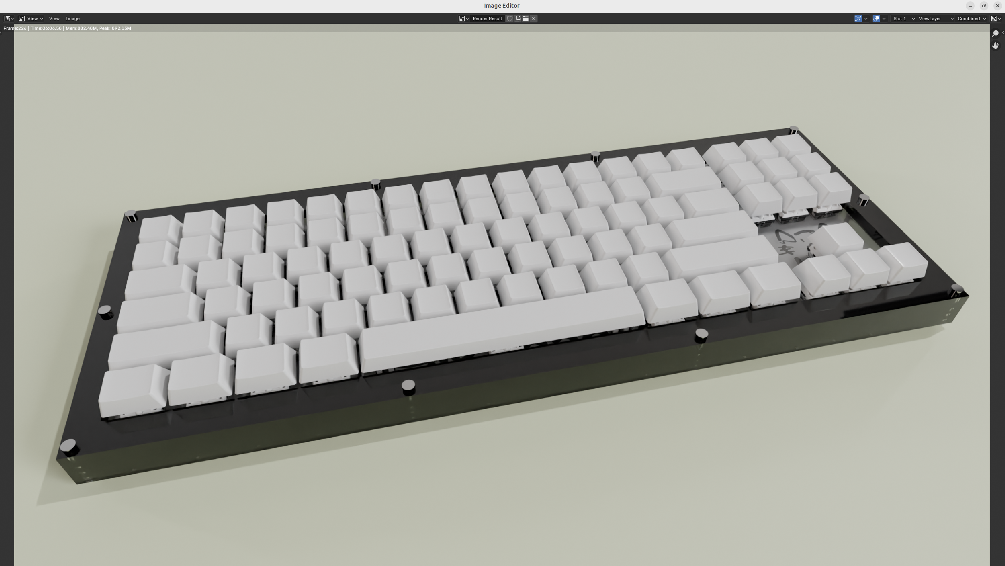
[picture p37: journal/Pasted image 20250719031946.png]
Pasted image 20250719031946.png


Now that looks pretty good, but I still want the acrylic to be kind of more see-through like the render preview, so I guess I'll have to mess around with the settings a bit more. But anyways I'm kind of too lazy to fix that, and now I just want to ship it out. 

Maybe sometime I'll get it working, but for now, I'll just use the Onshape render because that one looks more realistic to the actual thing.

That was quite a bit of time wasted, but I did learn a ton more about Blender which was nice.

Anyways, finally, I created the BOM, and now it's time to submit!

Pasted image 20250720012417.png

**Total time worked on this project: 23 hours (probably more than that, but this is a safe estimate)** 

## Day 5 - Assembly - 10 Hours

I just got my PCB in the main and all the parts, so time to solder and assemble:

Pasted image 20250807051407.png

I had both neopixels, keys and diodes so it was going to be LOTS of soldering.

First I started off by tinning ALL the pads of my neopixels. This makes it easy for them to solder. But trust me, this isn't ACTUALLY the first thing I did, first I tried to solder them in directly which didn't work, so I did a bit of research and came across this.

Anyways, tin all your pads, and then place a neopixel on the pad. Hold the neopixel with tweezers or something and then just press the solder onto a pad and it'll join it in place. Now you can just do the same for all the other pads and then apply the solder when you're done for a nice finish!

Next I did the diodes, it was pretty simple, just some THT so I applied heat to all three, the pad, the lead and the solder, and I think my soldering turned out pretty nice.

Pasted image 20250807051322.png

I forgot to mention, but I had a pi pico, so I kind of just like soldered it THT, it already had pin headers so it was nothing crazy.

Anyways, after that, I put in all the switches, which was just quite a bit of solder used to fill the big pads, but it turned out nicely.

I didn't get my case in time so I actually couldn't do plate mounted, but I'll just switch the CAD design a tad so it'll work.

After doing all the switches, I put all the keycaps on, and it was looking beautiful!

Pasted image 20250807051506.png

Now all I had to do was upload the firmware which was just adding it from my repository and it was up and running!

Again, I couldn't have gotten the neopixels up and running in time before my vacation, but it's a functioning keyboard which I'm happy with!

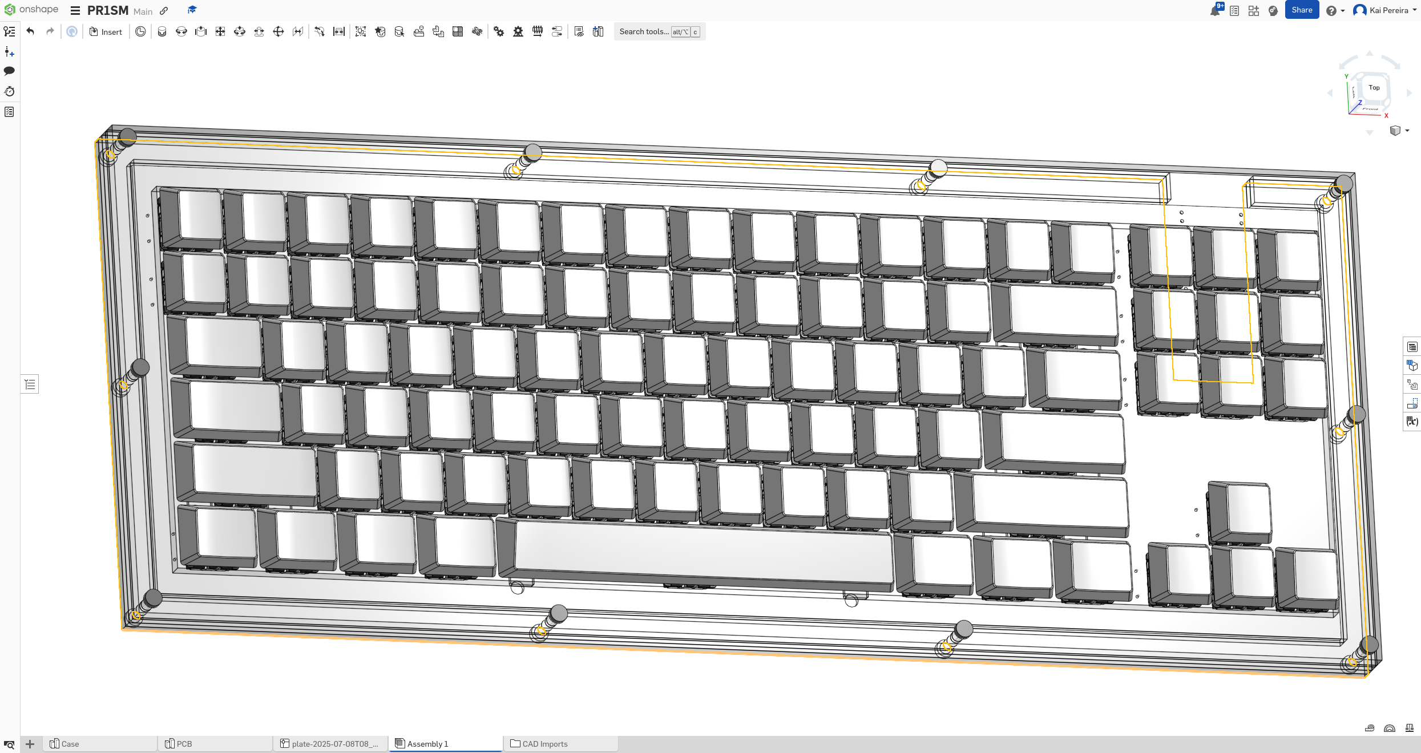
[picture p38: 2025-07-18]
journal/Pasted image 20250718021948.png

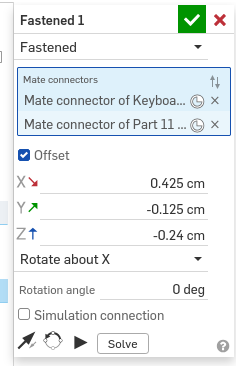
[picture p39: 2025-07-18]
journal/Pasted image 20250718022402.png

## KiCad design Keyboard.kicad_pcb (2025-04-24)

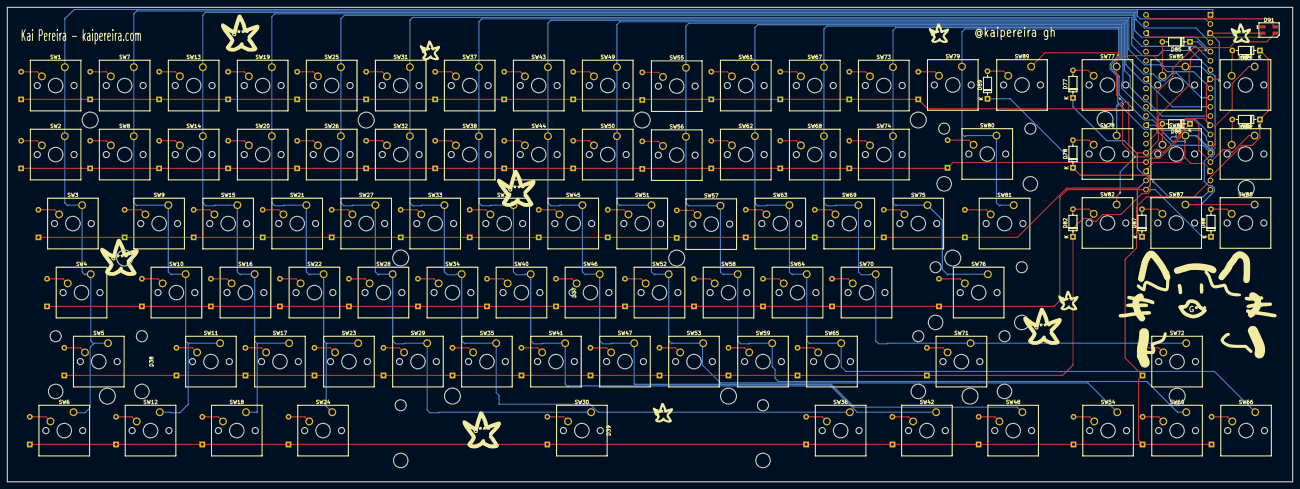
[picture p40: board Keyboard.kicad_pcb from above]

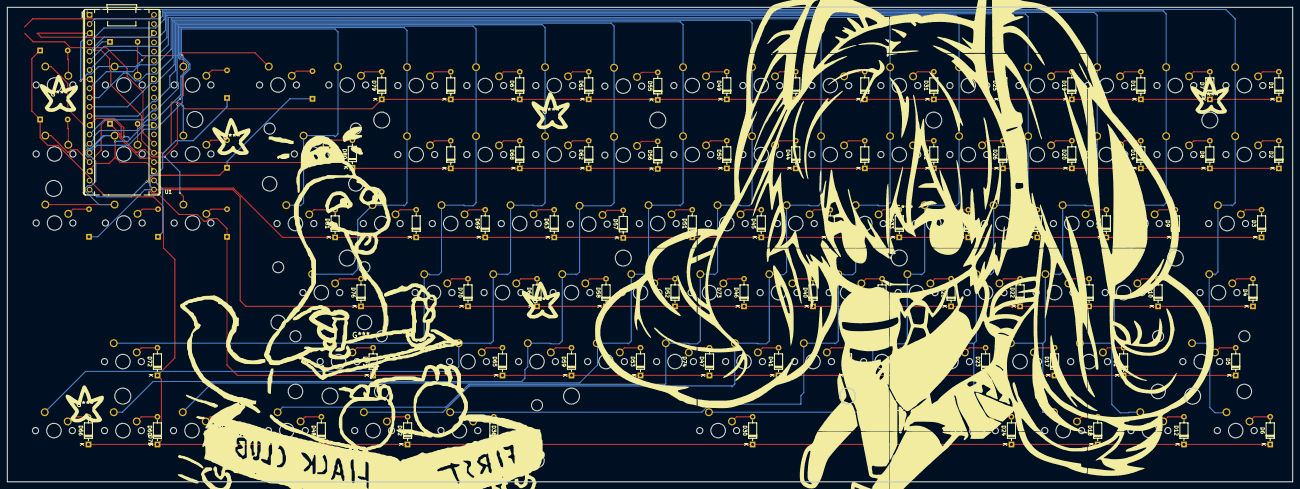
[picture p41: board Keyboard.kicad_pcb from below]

Board: 2 copper layers, 354.8 x 131.0 mm, 180 parts (80 on the bottom side), 113 nets.

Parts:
D1, D2, D3, D4, D5, D6, D7, D8, D9, D10, D11, D12, D13, D14, D15, D16, D17, D18, D19, D20, D21, D22, D23, D24, D25, D26, D27, D28, D29, D30, D31, D32, D33, D34, D35, D36, D37, D38, D39, D40, D41, D42, D43, D44, D45, D46, D47, D48, D49, D50, D51, D52, D53, D54, D55, D56, D57, D58, D59, D60, D61, D62, D63, D64, D65, D66, D67, D68, D69, D70, D71, D72, D73, D74, D75, D76, D77, D78, D79, D80, D81, D82, D83, D84, D85, D86, D87, D88, D89: 1N4148; D_DO-35_SOD27_P7.62mm_Horizontal
D91: SK6812MINI; LED_SK6812MINI_PLCC4_3.5x3.5mm_P1.75mm
SW1, SW2, SW7, SW8, SW9, SW10, SW11, SW13, SW14, SW15, SW16, SW17, SW19, SW20, SW21, SW22, SW23, SW25, SW26, SW27, SW28, SW29, SW31, SW32, SW33, SW34, SW35, SW37, SW38, SW39, SW40, SW41, SW43, SW44, SW45, SW46, SW47, SW49, SW50, SW51, SW52, SW53, SW54, SW55, SW56, SW57, SW58, SW59, SW60, SW61, SW62, SW63, SW64, SW65, SW66, SW67, SW68, SW69, SW70, SW72, SW73, SW74, SW75, SW77, SW78, SW79, SW82, SW83, SW84, SW85, SW86, SW87, SW88, SW89: SW_Push; SW_Cherry_MX_1.00u_PCB
SW3, SW81: SW_Push; SW_Cherry_MX_1.50u_PCB
SW4: SW_Push; SW_Cherry_MX_1.75u_PCB
SW5, SW76: SW_Push; SW_Cherry_MX_2.25u_PCB
SW6, SW12, SW18, SW24, SW36, SW42, SW48: SW_Push; SW_Cherry_MX_1.25u_PCB
SW30: SW_Push; SW_Cherry_MX_6.25u_PCB
SW71: SW_Push; SW_Cherry_MX_2.75u_PCB
SW80: SW_Push; SW_Cherry_MX_2.00u_PCB
U1: Pico; RaspberryPi_Pico_Common_THT

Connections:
+5V: D91.4 (VDD), U1.40 (VBUS)
Col 0: SW1.1, SW2.1, SW3.1, SW4.1, SW5.1, SW6.1, U1.1 (GPIO0)
Col 1: SW7.1, SW8.1, SW9.1, SW10.1, SW11.1, SW12.1, U1.2 (GPIO1)
Col 2: SW13.1, SW14.1, SW15.1, SW16.1, SW17.1, SW18.1, U1.4 (GPIO2)
Col 3: SW19.1, SW20.1, SW21.1, SW22.1, SW23.1, SW24.1, U1.5 (GPIO3)
Col 4: SW25.1, SW26.1, SW27.1, SW28.1, SW29.1, SW30.1, U1.6 (GPIO4)
Col 5: SW31.1, SW32.1, SW33.1, SW34.1, SW35.1, SW36.1, U1.7 (GPIO5)
Col 6: SW37.1, SW38.1, SW39.1, SW40.1, SW41.1, SW42.1, U1.9 (GPIO6)
Col 7: SW43.1, SW44.1, SW45.1, SW46.1, SW47.1, SW48.1, U1.10 (GPIO7)
Col 8: SW49.1, SW50.1, SW51.1, SW52.1, SW53.1, SW54.1, U1.11 (GPIO8)
Col 9: SW55.1, SW56.1, SW57.1, SW58.1, SW59.1, SW60.1, U1.12 (GPIO9)
Col 10: SW61.1, SW62.1, SW63.1, SW64.1, SW65.1, SW66.1, U1.14 (GPIO10)
Col 11: SW67.1, SW68.1, SW69.1, SW70.1, SW71.1, SW72.1, U1.15 (GPIO11)
Col 12: SW73.1, SW74.1, SW75.1, SW76.1, SW78.1, SW83.1, U1.16 (GPIO12)
Col 13: SW77.1, SW79.1, SW80.1, SW81.1, SW82.1, SW84.1, U1.17 (GPIO13)
Col 14: SW85.1, SW86.1, SW87.1, SW88.1, SW89.1
GND: D91.2 (VSS), U1.3 (GND), U1.8 (GND), U1.13 (GND), U1.18 (GND), U1.23 (GND), U1.28 (GND), U1.38 (GND)
LED: D91.3 (DIN), U1.26 (GPIO20)
unnamed: D1.2 (A), SW1.2
unnamed: D2.2 (A), SW2.2
unnamed: D3.2 (A), SW3.2
unnamed: D4.2 (A), SW4.2
unnamed: D5.2 (A), SW5.2
unnamed: D6.2 (A), SW6.2
unnamed: D7.2 (A), SW7.2
unnamed: D8.2 (A), SW8.2
unnamed: D9.2 (A), SW9.2
unnamed: D10.2 (A), SW10.2
unnamed: D11.2 (A), SW11.2
unnamed: D12.2 (A), SW12.2
unnamed: D13.2 (A), SW13.2
unnamed: D14.2 (A), SW14.2
unnamed: D15.2 (A), SW15.2
unnamed: D16.2 (A), SW16.2
unnamed: D17.2 (A), SW17.2
unnamed: D18.2 (A), SW18.2
unnamed: D19.2 (A), SW19.2
unnamed: D20.2 (A), SW20.2
unnamed: D21.2 (A), SW21.2
unnamed: D22.2 (A), SW22.2
unnamed: D23.2 (A), SW23.2
unnamed: D24.2 (A), SW24.2
unnamed: D25.2 (A), SW25.2
unnamed: D26.2 (A), SW26.2
unnamed: D27.2 (A), SW27.2
unnamed: D28.2 (A), SW28.2
unnamed: D29.2 (A), SW29.2
unnamed: D30.2 (A), SW30.2
unnamed: D31.2 (A), SW31.2
unnamed: D32.2 (A), SW32.2
unnamed: D33.2 (A), SW33.2
unnamed: D34.2 (A), SW34.2
unnamed: D35.2 (A), SW35.2
unnamed: D36.2 (A), SW36.2
unnamed: D37.2 (A), SW37.2
unnamed: D38.2 (A), SW38.2
unnamed: D39.2 (A), SW39.2
unnamed: D40.2 (A), SW40.2
unnamed: D41.2 (A), SW41.2
unnamed: D42.2 (A), SW42.2
unnamed: D43.2 (A), SW43.2
unnamed: D44.2 (A), SW44.2
unnamed: D45.2 (A), SW45.2
unnamed: D46.2 (A), SW46.2
unnamed: D47.2 (A), SW47.2
unnamed: D48.2 (A), SW48.2
unnamed: D49.2 (A), SW49.2
unnamed: D50.2 (A), SW50.2
unnamed: D51.2 (A), SW51.2
unnamed: D52.2 (A), SW52.2
unnamed: D53.2 (A), SW53.2
unnamed: D54.2 (A), SW54.2
unnamed: D55.2 (A), SW55.2
unnamed: D56.2 (A), SW56.2
unnamed: D57.2 (A), SW57.2
unnamed: D58.2 (A), SW58.2
unnamed: D59.2 (A), SW59.2
unnamed: D60.2 (A), SW60.2
unnamed: D61.2 (A), SW61.2
unnamed: D62.2 (A), SW62.2
unnamed: D63.2 (A), SW63.2
unnamed: D64.2 (A), SW64.2
unnamed: D65.2 (A), SW65.2
unnamed: D66.2 (A), SW66.2
unnamed: D67.2 (A), SW67.2
unnamed: D68.2 (A), SW68.2
unnamed: D69.2 (A), SW69.2
unnamed: D70.2 (A), SW70.2
unnamed: D71.2 (A), SW71.2
unnamed: D72.2 (A), SW72.2
unnamed: D73.2 (A), SW73.2
unnamed: D74.2 (A), SW74.2
unnamed: D75.2 (A), SW75.2
unnamed: D76.2 (A), SW76.2
unnamed: D77.2 (A), SW77.2
unnamed: D78.2 (A), SW78.2
unnamed: D79.2 (A), SW79.2
unnamed: D80.2 (A), SW80.2
unnamed: D81.2 (A), SW81.2
unnamed: D82.2 (A), SW82.2
unnamed: D83.2 (A), SW83.2
unnamed: D84.2 (A), SW84.2
unnamed: D85.2 (A), SW85.2
unnamed: D86.2 (A), SW86.2
unnamed: D87.2 (A), SW87.2
unnamed: D88.2 (A), SW88.2
unnamed: D89.2 (A), SW89.2
Row 0: D6.1 (K), D12.1 (K), D18.1 (K), D24.1 (K), D30.1 (K), D36.1 (K), D42.1 (K), D48.1 (K), D54.1 (K), D60.1 (K), D66.1 (K), D72.1 (K), D83.1 (K), D84.1 (K), U1.19 (GPIO14)
Row 1: D5.1 (K), D11.1 (K), D17.1 (K), D23.1 (K), D29.1 (K), D35.1 (K), D41.1 (K), D47.1 (K), D53.1 (K), D59.1 (K), D65.1 (K), D71.1 (K), D78.1 (K), D82.1 (K), D89.1 (K), U1.20 (GPIO15)
Row 2: D4.1 (K), D10.1 (K), D16.1 (K), D22.1 (K), D28.1 (K), D34.1 (K), D40.1 (K), D46.1 (K), D52.1 (K), D58.1 (K), D64.1 (K), D70.1 (K), D76.1 (K), D77.1 (K), D88.1 (K), U1.21 (GPIO16)
Row 3: D3.1 (K), D9.1 (K), D15.1 (K), D21.1 (K), D27.1 (K), D33.1 (K), D39.1 (K), D45.1 (K), D51.1 (K), D57.1 (K), D63.1 (K), D69.1 (K), D75.1 (K), D81.1 (K), D87.1 (K), U1.22 (GPIO17)
Row 4: D2.1 (K), D8.1 (K), D14.1 (K), D20.1 (K), D26.1 (K), D32.1 (K), D38.1 (K), D44.1 (K), D50.1 (K), D56.1 (K), D62.1 (K), D68.1 (K), D74.1 (K), D80.1 (K), D86.1 (K), U1.24 (GPIO18)
Row 5: D1.1 (K), D7.1 (K), D13.1 (K), D19.1 (K), D25.1 (K), D31.1 (K), D37.1 (K), D43.1 (K), D49.1 (K), D55.1 (K), D61.1 (K), D67.1 (K), D73.1 (K), D79.1 (K), D85.1 (K), U1.25 (GPIO19)

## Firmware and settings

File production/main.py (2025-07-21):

# NOTE THIS SCRIPT WAS MAJORITY AI GENERATED
# The neopixel wiring took quite a long time and iterations to get clean, so I don't really have too much time anymore :(
# I need to do quite a bit of testing to get the neopixels how I like em, so I'm just leaving it like that 
import board
from kmk.kmk_keyboard import KMKKeyboard
from kmk.scanners import DiodeOrientation
from kmk.keys import KC
from kmk.extensions.RGB import RGB
from kmk.modules.layers import Layers

import supervisor

keyboard = KMKKeyboard()

keyboard.diode_orientation = DiodeOrientation.COL2ROW

layers = Layers()
keyboard.modules.append(layers)

rgb_ext = RGB(
    pixel_pin=board.D0,
    num_pixels=87,
    hue_default=0, 
    sat_default=255,
    val_default=64,
    animation_mode=0
)
keyboard.extensions.append(rgb_ext)

keyboard.keymap = [
    [
        KC.ESC,  KC.F1,  KC.F2,  KC.F3,  KC.F4,  KC.F5,  KC.F6,  KC.F7,  KC.F8,  KC.F9,  KC.F10, KC.F11, KC.F12,
        KC.PRNT, KC.SLCK, KC.PAUS,
        KC.GRAVE, KC.N1, KC.N2, KC.N3, KC.N4, KC.N5, KC.N6, KC.N7, KC.N8, KC.N9, KC.N0, KC.MINS, KC.EQL, KC.BSPC,
        KC.INS, KC.HOME, KC.PGUP,
        KC.TAB, KC.Q, KC.W, KC.E, KC.R, KC.T, KC.Y, KC.U, KC.I, KC.O, KC.P, KC.LBRC, KC.RBRC, KC.BSLS,
        KC.DEL, KC.END, KC.PGDN,
        KC.CAPS, KC.A, KC.S, KC.D, KC.F, KC.G, KC.H, KC.J, KC.K, KC.L, KC.SCLN, KC.QUOT, KC.ENTER,
        KC.LSFT, KC.Z, KC.X, KC.C, KC.V, KC.B, KC.N, KC.M, KC.COMM, KC.DOT, KC.SLSH, KC.RSFT,
        KC.LCTL, KC.LGUI, KC.LALT, KC.SPC, KC.RALT, KC.RGUI, KC.MENU, KC.RCTL
    ]
]

keyboard.keymap[0][0] = KC.TO(0) 
keyboard.keymap[0][1] = KC.RGB_TOG
keyboard.keymap[0][2] = KC.RGB_MOD
keyboard.keymap[0][3] = KC.RGB_HUI
keyboard.keymap[0][4] = KC.RGB_HUD
keyboard.keymap[0][5] = KC.RGB_SAI
keyboard.keymap[0][6] = KC.RGB_SAD
keyboard.keymap[0][7] = KC.RGB_VAI 
keyboard.keymap[0][8] = KC.RGB_VAD  

if __name__ == '__main__':
    keyboard.go()

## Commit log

2025-04-14 pcb files
    [Keyboard.kicad_pcb, Keyboard.kicad_sch, Keyboard.step]
2025-04-16 added holes to my pcb
    [Keyboard.kicad_pcb]
2025-04-16 fix some drc errors
    [Keyboard.kicad_pcb]
2025-04-16 updated footprints, didnt rlly seem to work lol
    [Keyboard.kicad_sch]
2025-04-16 more footprint stuff
    [Keyboard.kicad_pcb]
2025-04-17 some more pcb stuff
    [Keyboard.kicad_pcb]
2025-04-24 updating pcb
    [Keyboard.kicad_pcb, Keyboard.kicad_sch]
2025-07-09 adding files
    [Keyboard.kicad_sch, switch.step]
2025-07-09 fixed all drc errors on the pcb and optimize the power a bit more
2025-07-10 added 3d models to keys
    [Keyboard.kicad_sch]
2025-07-10 added silkscreen to PCB
2025-07-10 added new silkscreen to pcb
2025-07-10 adding some 3d models
    [Keyboard.kicad_sch]
2025-07-10 3d models and updated footprints
    [Keyboard.kicad_sch]
2025-07-16 some pcb stuff
2025-07-17 added journal and some other stuff
    [Keyboard.kicad_sch, switch.step]
2025-07-18 updating the pcb and added the firmware file
2025-07-18 another pcb update
2025-07-18 added the CAD files
    [Full Case.step, Layer 1 Case.step, Layer 2 Case.step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]
2025-07-18 added render and renaming some files
    [Keyboard.kicad_sch, switch.step]
2025-07-18 added render file to lfs and renamed pcb folder
2025-07-18 adding render.blend via LFS
    [render.blend]
2025-07-19 updated the pcb and some blender stuff
    [render.blend]
2025-07-19 added blend1 file to lfs and some pcb stuff
2025-07-19 updated the journal a bit and some pcb stuff
2025-07-19 updated the blender file and also some pcb stuff
    [render.blend]
2025-07-19 adding somre more blender stuff
    [render.blend]
2025-07-19 adding in my HDRI and some more blender stuff
    [Full Case.obj]
2025-07-19 forgot some blender stuff
    [render.blend]
2025-07-19 added HDRI to blender render
    [render.blend]
2025-07-19 did some case stuff for the render
    [render.blend]
2025-07-19 updating the render
    [render.blend]
2025-07-19 added new render and stuff
    [render.blend]
2025-07-19 actually moved the pcb now instead of animating
    [render.blend]
2025-07-19 updated render and did some more lender stuff
    [render.blend]
2025-07-19 finished writing journal
    [render.blend]
2025-07-20 some production files
    [Full Case.step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]
2025-07-20 updated journal and added BOM
    [BOM.csv]
2025-07-20 added pcb photo's
2025-07-21 Added keycaps to BOM
    [BOM.csv]
2025-07-25 updated spreadsheet
    [BOM.csv]
2025-07-25 updated readme bom
2025-08-19 update with dxf's
    [1.5mm PLATE.dxf, 3.5mm BOTTOM.dxf, 3.5mm SPACER-PRINT_2.dxf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]
